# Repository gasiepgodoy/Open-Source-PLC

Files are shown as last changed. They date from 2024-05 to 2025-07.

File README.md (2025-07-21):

# Open-Source-PLC

**Open-Source-PLC** is an open automation platform developed as part of a master's degree project, focused on accessibility, customization, and compatibility with both industrial and educational applications. The goal is to democratize access to industrial automation through a fully open, documented hardware and software solution based on widely adopted technologies.

This repository centralizes all files, documentation, schematics, and source code required to understand, replicate, and extend the system—ensuring long-term continuity and community collaboration.

---

## 🎯 Project Purpose

For an open-source platform to be truly applicable in industrial settings, it must go beyond basic functionality and meet criteria for engineering quality, physical robustness, and scalability. Therefore, the following strategic requirements were defined:

- Full Openness: The project provides complete access to all hardware files (schematics, PCB layout, BOM) and software libraries with public documentation, enabling full transparency, replication, and community-driven evolution.
- Flexibility and Customization: The modular hardware design, combined with support for multiple languages and protocols, allows the platform to be adapted to a variety of processes, from test benches to full-scale industrial lines.
- Industrial Compatibility: The adoption of industrial voltage levels, standard connectors, and protocols such as Modbus and MQTT ensures direct adherence to realworld industrial operating conditions.
- Low Learning Curve: The use of familiar environments (OpenPLC Editor, Thonny IDE) and the development of simplified MicroPython libraries make the platform accessible even to teams with limited experience in advanced programming.
- Experimental Feasibility and Scalability: The architecture has been validated in two distinct setups (PID control and part-sorting station), demonstrating its ability to operate reliably in real applications while remaining scalable for future expansions. 

This combination of elements allows the solution to serve as a bridge between the maker/open-source ecosystem and the technical demands of industry, fostering an environment of continuous innovation, operational cost reduction, and greater technological freedom.

---

## ⚙️ Functional Requirements

- Support for both MicroPython and IEC 61131-3 (via OpenPLC)
- Digital and analog input/output, PWM support
- Ethernet communication (via W5500), with MQTT protocol
- Encoder interface and compatibility with industrial sensors
- Compatibility with standard industrial protocols and connectors
- Modular hardware design with plug-and-play expandability

---

## 🧩 Hardware Summary

The architecture is organized into independent functional blocks, with modular I/O expansion via SPI serialization, allowing the number of inputs and outputs to be tailored to the specific application. The base version of the platform includes:

- **Main controller:** Raspberry Pi Pico (RP2040)
- **Expansion:** Up to 12 digital inputs, 8 digital outputs, 1 dedicated PWM output, 4 analog inputs, and 1 encoder input
- **Networking:** W5500 Ethernet chip with RJ45 connector, SPI communication
- **Electrical Interface:** Level shifters, opto-isolated inputs, and industrial-grade buffers
- **Additional Support:** Optional RS-232/RS-485 communication bus

All schematics and PCB layout files are available in the [`/Hardware`](./Hardware) folder.

---

## 🖥️ Software Summary

The platform offers native support for two complementary paradigms:

### MicroPython
which supports high-level scripting for control, communication, and integration with platforms such as Node-RED, databases, and dashboards.

### OpenPLC
which enables the development of control logic using IEC 61131-3 standardized languages such as Ladder and Structured Text, with an accessible development environment

More details are available in the [`/Software`](./Software) folder.

---

## 🔬 Validation and Testing

Two practical experiments were conducted to validate the system's functionality:

1. **DC Motor PID Control (MicroPython):**
   - Speed control using encoder feedback
   - MQTT communication with Node-RED
   - Validation through manual shaft load variation

2. **Color Sorting Station (OpenPLC):**
   - Color detection with automated part separation
   - Controlled via ladder logic
   - Monitored through MQTT and Node-RED dashboards

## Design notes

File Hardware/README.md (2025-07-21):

# 🧩 Hardware Details – Open-Source-PLC

This section provides an overview of the hardware developed for the Open-Source-PLC platform. The system was designed to be open, modular, and compatible with both industrial devices and educational environments. All design files, schematics, and PCB layouts are included in the repository for replication or adaptation.

---

## 1. 🧱 Architecture Overview

The hardware architecture was based on the following core principles:

- **Modularity:** Independent functional blocks (I/O, communication, power, etc.)
- **Openness:** All design files (schematics, layouts, BOM) are fully available
- **Compatibility:** Designed for use with sensors, actuators, and protocols commonly found in industrial systems
- **Accessibility:** Easily programmable using MicroPython or OpenPLC

---

## 2. 🔧 Main Components

| Component | Description |
|---|---|
| **Microcontroller** | Raspberry Pi Pico (RP2040) |
| **Ethernet Interface** | W5500 chip with SPI interface and RJ45 connector |
| **Digital Inputs** | Up to 12 channels, opto-isolated |
| **Digital Outputs (PWM)**  | 2 PWM-capable outputs with transistor drivers |
| **Analog Inputs** | 4 channels, -10 – 10 V (external sensors, potentiometers) |
| **Encoder Input** | Incremental encoder interface (A/B channels with interrupt support) |
| **Power Supply** | 24 V DC input with onboard voltage regulation |
| **Protection** | ESD protection, buffering, opto-isolators, flyback diodes for outputs |
| **Optional** | RS-232 / RS-485 transceivers for future protocol expansions |

---

## 3. 🧾 PCB and Schematics

All design files are located in the [`hardware`](../hardware) folder. This includes:

- Schematics in PDF and source format (KiCad)
- PCB layout and 3D view files
- Bill of Materials (BOM)
- Gerber files ready for fabrication

---

## 4. 🧰 Assembly and Integration

The hardware is designed to be easily assembled using through-hole and SMD components. Key integration considerations:

- Headers and terminal blocks follow a modular layout for easier cabling
- The platform includes pin labeling and silkscreen guidance
- Power input protection and reverse polarity safeguards included

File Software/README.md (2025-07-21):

# 🧠 Software Implementation Overview – MicroPython and OpenPLC

This document provides a general overview of the software implementations used in the Open-Source-PLC platform. The system was designed to support two complementary development environments:

- **OpenPLC**, an open-source platform that supports IEC 61131-3 programming languages (Ladder, Structured Text, etc.)
- **MicroPython**, a high-level scripting language adapted for microcontrollers, allowing flexible and modular control logic

The goal was to enable the platform to support both industry-standard and educational/research-friendly environments.

---

## 🔷 OpenPLC – IEC 61131-3-Based Programming

OpenPLC was used to validate the compatibility of the hardware with traditional industrial programming standards.

### ✅ Key Features Implemented:
- Integration with **OpenPLC Runtime** on the Raspberry Pi Pico 
- Development of a **color-sorting station** controlled entirely in **Ladder Diagram**
- Use of digital inputs for sensors and digital outputs for actuators
- Real-time monitoring via **MQTT and Node-RED dashboards**

### 🧩 Custom Function Blocks:
To enhance functionality and simplify reuse, custom blocks were created:
- **MQTT Interface Logic:** State variables exposed for integration with Node-RED

### 🧪 Application Example:
- The system uses a color sensor connected to a digital input
- Based on the detected color, an actuator is triggered to sort parts
- Status and results are published to a Node-RED dashboard via MQTT

More technical details will be available in [`OpenPLC/`](../Software/OpenPLC/).

---

## 🟢 MicroPython – Modular High-Level Control

MicroPython was used to develop a fully custom control application and validate the hardware using real-time scripting and communication.

### ✅ Key Features Developed:
- **Modular library** to abstract all I/O operations (Digital I/O, PWM, Analog, Encoder, Ethernet)
- Implementation of a **PID control loop** for DC motor speed using encoder feedback
- Real-time variable update and remote control via **MQTT**
- Integration with **Node-RED** for visualization and manual control

### 📦 Library Modules:
The custom MicroPython library includes:
- `DigitalIO` – digital input/output abstraction
- `PWMOutput` – PWM signal control with frequency and duty cycle options
- `AnalogInput` – basic analog reading with scaling support
- `Encoder` – quadrature encoder interface with real-time position/velocity
- `Ethernet` – W5500 communication interface with DHCP or static IP setup

### 🧪 Application Example:
- A DC motor is controlled via PWM
- An encoder provides speed feedback
- A PID algorithm adjusts the PWM to maintain desired RPM
- MQTT is used to receive setpoints and send actual speed to Node-RED

More technical details will be available in [`Micropython/`](../Software/Micropython/).

---

## 🔄 Coexistence of OpenPLC and MicroPython

Although OpenPLC and MicroPython are used in different contexts, they share the same hardware infrastructure. The platform supports:

- Independent flashing of either OpenPLC Runtime or MicroPython firmware
- Shared access to GPIOs, communication buses, and external interfaces
- Common interfaces with MQTT and Node-RED, allowing seamless monitoring regardless of backend

This dual-approach design enables the platform to be used in:
- **Industrial control scenarios** with standard IEC languages
- **Research and prototyping** using rapid development with MicroPython

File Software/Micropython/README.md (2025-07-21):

# MicroPython Firmware Overview

This section details the developments made using MicroPython on the Open-Source-PLC platform. MicroPython was chosen for its ease of use, flexibility, and compatibility with embedded systems, enabling fast prototyping and direct interaction with hardware.

## Purpose and Justification

The use of MicroPython in this project aimed to:

- Enable a high-level programming alternative to IEC 61131-3, reducing the entry barrier for new users.
- Allow rapid testing and customization of control strategies without complex toolchains.
- Leverage open tools and existing MicroPython support on the RP2040 (Raspberry Pi Pico).

## Firmware Architecture

The firmware follows a modular architecture centered around a custom-developed library named `jaguar`, which abstracts access to the hardware resources of the automation platform.

### Key Modules

- **Digital I/O**: Easy mapping and handling of digital inputs and outputs.
- **Analog I/O**: Support for reading analog sensors and controlling outputs.
- **PWM Output**: Allows precise control of actuators such as motors.
- **Encoder**: Interface for reading motor or shaft position using quadrature encoders.
- **Ethernet (W5500)**: Enables communication with external systems via MQTT over Ethernet.

## Jaguar Library

The core of the firmware is the `jaguar` library, created specifically to make hardware programming more intuitive and abstracted. It provides a set of classes that simplify the use of GPIO, ADC, PWM, encoders, and network connectivity.

### Main Features

- Simple pin mapping system aligned with the platform’s labeling.
- Built-in compatibility with the RP2040 hardware features.
- MQTT-ready interface via W5500 Ethernet chip.
- Easy integration with dashboards and external monitoring tools (e.g., Node-RED).

## MQTT and Real-Time Communication

The firmware uses the `umqtt.simple` library to implement publish/subscribe communication via MQTT. This allows real-time data exchange between the controller and a remote dashboard or data logger.

### Applications

- Remote monitoring of motor speed, encoder position, and control parameters.
- Real-time update of PID parameters from a web interface.
- Logging of system behavior under varying load conditions.

## PID Control Use Case

A complete PID loop was implemented to control a DC motor’s speed using feedback from a quadrature encoder. The system supports real-time adjustment of PID parameters via MQTT and maintains target RPM despite manual load variations.

## Development Environment

- **Firmware Language**: MicroPython (latest stable)
- **IDE**: Thonny IDE
- **Board**: Raspberry Pi Pico
- **Network**: W5500 Ethernet via SPI
- **External Tool**: Node-RED (for visualization)

## Conclusion

The MicroPython firmware, paired with the custom `jaguar` library, enabled the Open-Source-PLC to serve not only as a traditional automation controller but also as a flexible experimentation platform. Its modular design, real-time communication capabilities, and ease of programming make it an ideal solution for educational, experimental, and IIoT applications.

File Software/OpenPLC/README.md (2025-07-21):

# OpenPLC Integration Overview

This section documents the adaptations, extensions, and validation of the OpenPLC framework on the Open-Source-PLC platform. OpenPLC was selected due to its compliance with the IEC 61131-3 standard, open-source nature, and flexibility for embedded applications.

## Purpose and Context

The integration of OpenPLC into the hardware platform aimed to:

- Validate the compatibility of the custom hardware with standard industrial automation software.
- Demonstrate the use of IEC 61131-3 languages (LD, ST, FBD, etc.) on open hardware.
- Provide an alternative path for users familiar with PLC programming.

## Hardware Compatibility

The hardware was adapted to be recognized by the OpenPLC runtime. This included:

- Setting up correct GPIO mapping on the Raspberry Pi Pico (RP2040).
- Developing a compatible hardware layer using the OpenPLC Embedded runtime.
- Ensuring electrical interface compatibility with standard sensors and actuators (24V DC logic, relay modules, etc.).

## Firmware Customizations

Several adaptations were made to the OpenPLC firmware to support the custom hardware:

- **Pin Mapping Layer**: A dedicated mapping file was created to align logical I/Os in the OpenPLC Editor with physical pins on the board.
- **Startup Sequence**: Modified initialization code to work with the board’s peripherals and power-on behavior.
- **I/O Expansion Support**: Extensions to support multiplexed or serialized I/Os.

## Function Block Development

Custom function blocks were developed and tested to enhance OpenPLC’s capabilities:

All blocks were created using the **Structured Text (ST)** language, and are included in the repository as `.st` or `.xml` files for reuse.

## Example Application: Color Sorting Station

A complete application was developed using OpenPLC to automate a color-based separation process.

### Overview

- A TCS230 color sensor detects object color.
- OpenPLC reads the sensor and triggers actuators (e.g., air jets or conveyors) based on the detected color.
- The system is fully programmable and customizable using the OpenPLC Editor.

### Runtime Details

- Program written in OpenPLC Editor (FBD + ST).
- Downloaded to board running OpenPLC Embedded runtime.
- I/Os monitored in real-time via the OpenPLC Web Interface.

## Development Tools

- **Editor**: OpenPLC Editor (IEC 61131-3 compliant)
- **Runtime**: OpenPLC for RP2040 Embedded (customized)

## Conclusion

The successful integration of OpenPLC on the Open-Source-PLC platform demonstrates its suitability for educational and industrial control systems. It enables users to program the controller using standardized IEC languages while benefiting from the openness and flexibility of custom hardware.

This hybrid approach allows for experimentation, interoperability, and easier learning for students and professionals alike.

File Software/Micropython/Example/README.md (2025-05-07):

# Open-Source-PLC - Micropython Validation

To validate the applicability of MicroPython on the developed platform, a detailed test scenario was structured, designed to evaluate the system's capabilities in industrial process control. The experiment involves the implementation of a PID speed control, demonstrating the platform's capabilities in applications that require precision and dynamic response.

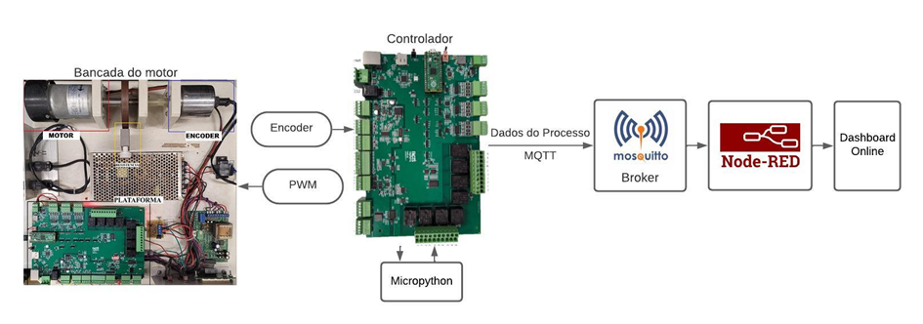
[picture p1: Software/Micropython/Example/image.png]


A video of the experiment can be found at: https://youtu.be/rbEFqCIbv0c?si=TKTA0UZk-yRIU58f

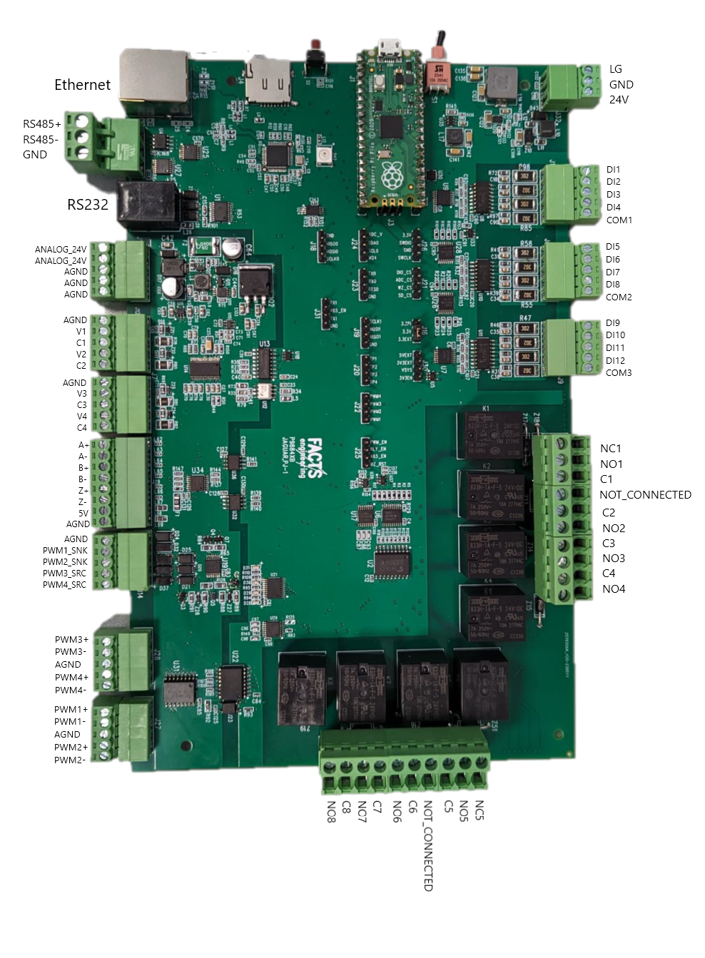
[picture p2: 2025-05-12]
Hardware/Project Pinout.png

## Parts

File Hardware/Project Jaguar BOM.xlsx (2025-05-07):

Level | Item | Part Number | Qty | Refdes | Description | Rev | Vendor | Vendor Part Number
1 | 1 | 1150-00154 | 7 | C1,C5,C7,C9,C48,C56,C81 | .01UF,25V,10%,Ceramic,X7R,0402 | - | TDK | C1005X7R1E103K050BB
1 | 2 | 1150-00120 | 70 | C2-4,C6,C8,C10,C12-14,C17,C19-23,C39,C41,C43,C45,C50-55,C57,C68-69,C72,C74-75,C77,C80,C82-85,C91-92,C94-95,C99-108,C112-113,C115-117,C119,C124-132,C166,C168,C170,C308 | .1UF,50V,10%,Ceramic,X7R,0402 | - | Murata | GRM155R71H104KE14D
 |  |  |  |  |  |  | TDK | C1005X7R1H104K050BB
1 | 4 | 1150-00066 | 1 | C11 | 2200PF,100V,5%,Ceramic,COG,1206 | A1 | AVX | 12061A222JAT2A
 |  |  |  |  |  |  | Prosperity Dielectrics Co., Ltd. | MA1206CG-222J-101PRG
 |  |  |  |  |  |  | Yageo America | CC1206JRNPO0BN222
 |  |  |  |  |  |  | SINCERA-WALSIN | 1206N222J101LT
1 | 7 | 1150-00014 | 13 | C18,C31-38,C42,C88-90 | .1UF,100V,10%,Ceramic,X7R,0805 | A1 | Murata | GCM21BR72A104KA37L
 |  |  |  |  |  |  | Prosperity Dielectrics Co., Ltd. | MA0805XR-104K-101PRG
 |  |  |  |  |  |  | SINCERA-WALSIN | 0805B104K101CT
1 | 9 | 1150-00050 | 9 | C15,C24,C26-28,C30,C40,C65,C67 | 1UF,10V,10%,Ceramic,X5R,0603 | A1 | AVX | 0603ZD105KAT2A
 |  |  |  |  |  |  | Prosperity Dielectrics Co., Ltd. | MA0603XR-105K-100PRG
 |  |  |  |  |  |  | SINCERA-WALSIN | 0603X105K160CT
1 | 10 | 1150-00029 | 3 | C25,C141-142 | 22UF,25V,+/-10%,Ceramic,X5R,1206 | - | Murata | GRM31CR61E226KE15L
 |  |  |  |  |  |  | SINCERA-WALSIN | 1206X226K250CT
 |  |  |  |  |  |  | Prosperity Dielectrics Co., Ltd. | MA1206XR-226K-250PRG
 |  |  |  |  |  |  | Samsung | CL31A226KAHNNNE
1 | 13 | 1150-00004 | 7 | C16,C44,C70,C76,C78-79,C109 | .001UF,50V,10%,Ceramic,X7R,0603 | A1 | Murata | GRM188R71H102KA01D
 |  |  |  |  |  |  | Prosperity Dielectrics Co., Ltd. | MA0603XR-102K-500PRG
 |  |  |  |  |  |  | Yageo America | CC0603KRX7R9BB102
 |  |  |  |  |  |  | SINCERA-WALSIN | 0603B102K500CT
1 | 14 | 1150-00178 | 4 | C29,C46-47,C140 | 10UF,10V,10%,Ceramic,X5R,0603 | - | Murata | GRM188R61A106KE69J
 |  |  |  |  |  |  | AVX | 0603ZD106KAT2A
 |  |  |  |  |  |  | TDK | C1608X5R1A106K080AC
 |  |  |  |  |  |  | Yageo America | CC0603KRX5R6BB106
1 | 16 | 1150-00007 | 1 | C123 | .01UF,50V,10%,Ceramic,X7R,0603 | A1 | Murata | GRM188R71H103KA01D
 |  |  |  |  |  |  | Yageo Corporation | CC0603KRX7R9BB103
 |  |  |  |  |  |  | Prosperity Dielectrics Co., Ltd. | MA0603XR-103K-500PRG
 |  |  |  |  |  |  | SINCERA-WALSIN | 0603B103K500CT
1 | 17 | 1150-00081 | 4 | C58-59,C61-62 | 4.7UF,25V,20%,Ceramic,X5R,0805 | A1 | Panasonic | ECJ-2FB1E475M
 |  |  |  |  |  |  | SINCERA-WALSIN | 0805X475K250CT
 |  |  |  |  |  |  | Prosperity Dielectrics Co., Ltd. | MA0805XR-475K-250PRG
 |  |  |  |  |  |  | Murata | GRM21BR61E475MA12L
1 | 18 | 1150-00084 | 1 | C63 | 470PF,50V,5%,Ceramic,COG,0805 | A1 | AVX | 08055A471JAT2A
 |  |  |  |  |  |  | Prosperity Dielectrics Co., Ltd. | MA0805CG-471J-PRG
 |  |  |  |  |  |  | SINCERA-WALSIN | 0805N471J500LT
1 | 19 | 1160-00016 | 1 | C64 | 22UF,50V,20%,Electrolytic,2000H@105C,6.3X5.8MM | A | Gemcon | GDX022M050-0605TR
1 | 20 | 1160-00021 | 2 | C66,C121 | 100UF,16V,20%,Electrolytic,2000H@105C,6.3X5.4mm | A | Gemcon | GCK100M016-0605TR
 |  |  |  |  |  |  | Gemcon | GDR100M016-0605TR
 |  |  |  |  |  |  | Nichicon | UWX1C101MCL1GB
1 | 21 | 1150-00002 | 3 | C49,C71,C73 | 4.7UF,10V,10%,Ceramic,X5R,0603 | A1 | Tai Yao | LMK107BJ475KA-T
 |  |  |  |  |  |  | Samsung | CL10A475KP8NNNC
 |  |  |  |  |  |  | Walsin Technology Corporation | 0603X475K160CT
1 | 23 | 1150-00063 | 6 | C86-87,C93,C96-98 | 20PF,50V,5%,Ceramic,COG,0603 | A1 | Murata | GRM1885C1H220JA01D
 |  |  |  |  |  |  | Prosperity Dielectrics Co., Ltd. | MA0603CG-200J-500PRG
 |  |  |  |  |  |  | SINCERA-WALSIN | 0603N200J500LT
1 | 27 | 1150-00064 | 1 | C122 | 2200PF,50V,10%,Ceramic,X7R,0603 | A1 | AVX | 06035C222KAT2A
1 | 28 | 1150-00041 | 1 | C135 | 10UF,35V,+/-10%,Ceramic,X5R,1206 | - | Taiyo Yuden | GMK316BJ106KL-T
1 | 29 | 1150-00118 | 1 | C139 | 27PF,50V,5%,Ceramic,COG,0402 | - | Murata | GRM1555C1H270JA01D
1 | 30 | 1375-00017 | 24 | D1-16,D28-31,D38-41 | LED,SMD,1.6x.8MM,Red | B1 | Taiwan Oasis | TO-1608BC-MRE
 |  |  |  |  |  |  | Harvatek | HT-191USD-DT
1 | 31 | 1300-00028 | 1 | D18 | Diode,Schottky,B1100,SMA | A1 | Diodes Inc | B1100-13-F
1 | 32 | 1375-00019 | 6 | D19,D22-23,D26-27,D34 | LED,SMD,3x1MM,Right Angle,Green | A1 | Taiwan Oasis | TO-3210AC-MGE (E2-E4)
 |  |  |  |  |  |  | Harvatek | HT-110UYG-CT
1 | 33 | 1350-00026 | 4 | D20-21,D24-25 | TVS, Unidirectional,SMAJ28A-TR,32.7V,400W,DO-214AC | - | ST | SMAJ28A-TR
 |  |  |  |  |  |  | Willas | SMAJ28A-TG
 |  |  |  |  |  |  | Goodwork | SMAJ28A
1 | 34 | 1300-00044 | 5 | D32-33,D36-37,D44 | Diode,Schottky,5819,SMA | A2 | SEP Electronics | SM5819
 |  |  |  |  |  |  | Formosa MS | FM5819
1 | 35 | 1300-00088 | 1 | D35 | Diode,Schottky,MBR0530T1G,SOD-123 | - | ON Semiconductor | MBR0530T1G
 |  |  |  |  |  |  | CZ | B0530W
1 | 36 | 1375-00035 | 1 | D42 | LED,SMD, Right Angle, 3.8x1.0MM, RGB with Integrated Serial Driver | - | RAMTRONICS INDUSTRIAL CO., LTD. | KR-3810
1 | 37 | 1300-00067 | 1 | D43 | Diode,Schottky,SM240A,SMA | A | GW | SM240A
 |  |  |  |  |  |  | Willas | SS24A
 |  |  |  |  |  |  | Diodes Inc | B240A-13-F
1 | 38 | 3001-00011 | 2 | J1-2 | Pin Header,1x20,2.54MM,SIP,Straight | - | AUK Contractors | HD1x20
1 | 39 | 3001-00001 | 2 | J3,J16 | Pin Header,1x3,2.54MM,SIP,Straight | - | AUK Contractors | HD1x03
1 | 40 | 3000-00110 | 1 | J4 | MircoSD,SMD,Receptical,9 | A1 | King Font | TFCMF-30801B0T1
 |  |  |  |  |  |  | King Font | TFCMF-30801B0T1-G
1 | 41 | 3000-00102 | 1 | J5 | RJ45,Shielded,With XFMR, RX/TX LEDS,12 | - | Kinsun | 3070130108
1 | 42 | 3030-00008 | 9 | J6-7,J9-12,J14,J27-28 | Terminal Block Socket,3.5MM,Right Angle,Closed End,Green,5 | A1 | Dinkle | ECH350R-05P
1 | 43 | 3030-00026 | 2 | J8,J15 | Terminal Block Socket,5MM,Vertical Angle, Closed End, Green,10 | - | Dinkle | 5EHDVC-10P
1 | 44 | 3030-00003 | 1 | J13 | Terminal Block Socket,5MM,Right Angle,Closed End,Green,3 | B1 | Dinkle | 5EHDRC-03P
1 | 45 | 3000-00037 | 1 | J17 | RJ12,Side,6 | A | Kinsun | 3004BE3600
1 | 46 | 3001-00002 | 10 | J18-26,J30 | Pin Header,1x4,2.54MM,SIP,Straight | - | AUK Contractors | HD1x-04
1 | 48 | 3030-00022 | 1 | J32 | Terminal Block Socket,3.5MM,Right Angle,Closed End,Green,Raised,3 | - | Dinkle | ECH350H-03P
1 | 49 | 3200-00026 | 2 | K1,K5 | Relay,1C,24VDC,277VAC/10A,125VAC/15A,30VDC/7A,833H-1C-24 | - | Song Chuan | 833H-1C-F-S-24VDC
1 | 50 | 3200-00027 | 6 | K2-4,K6-8 | Relay,1A,24VDC,277VAC/10A,125VAC/15A,30VDC/7A,833H-1A-24 | A | Song Chuan | 833H-1A-F-S-24VDC
1 | 51 | 1550-00008 | 4 | L1-4 | Ferrite,33 Ohm @100MHZ,0603 | A1 | Murata | BLM18PG330SN1D
 |  |  |  |  |  |  | Chilisin Electronics Corp | PBY160808T-330Y-N
 |  |  |  |  |  |  | VIKING | CB03YTYH330
1 | 52 | 1550-00003 | 1 | L5 | Ferrite,470 Ohm @100MHZ,0805 | A | Murata | BLM21AG471SN1D
1 | 53 | 1550-00007 | 2 | L6,L13 | Ferrite,220 Ohm @100MHZ,0603 | A1 | Murata | BLM18BD221SN1D
 |  |  |  |  |  |  | ABC Taiwan Electronics | MU1608221Y2B
1 | 54 | 1550-00006 | 6 | L7,L9,L11-12,L68-69 | Ferrite,330 Ohm @100MHZ,0805 | B2 | TDK | MPZ2012S331AT
 |  |  |  |  |  |  | ABC Taiwan Electronics | MB2029331Y2B
 |  |  |  |  |  |  | Hilisin | PBY201209T-331Y-N
1 | 55 | 1500-00056 | 1 | L8 | Inductor,Power,Shielded Ferrite Core,SMD,22UH,530MA | A | ABC Taiwan Electronics | SH4022220YLB
1 | 56 | 1500-00119 | 1 | L10 | Inductor,Chip Common Mode Choke Coil,1.4K @100MHz,2.0A | - | Murata Manufacturing | DLW5BTM142TQ2
1 | 57 | 1500-00010 | 1 | L14 | Inductor,Power,Shielded Ferrite Core,SMD,100UH,1.25A | - | Chilisin Electronics Corp | SCDS105RT-101-N
1 | 58 | 1500-00034 | 1 | L17 | Inductor,Power,Shielded Ferrite Core,SMD,2.2UH,1.6A | B | ABC Taiwan Electronics | SH40222R2YLB
1 | 59 | 1550-00004 | 2 | L25-26 | Ferrite,60 Ohm @100MHZ,0805 | A1 | Murata | BLM21PG600SN1D
 |  |  |  |  |  |  | Chilisin Electronics Corp | BBPY00201209600Y00
 |  |  |  |  |  |  | ABC Taiwan Electronics | MB2029221Y3B
1 | 61 | 1550-00014 | 6 | L62-67 | Ferrite,1K @100MHZ,0402 | - | Chilisin Electronics Corp | HFY100505T-102Y-N
 |  |  |  |  |  |  | Murata | BLM15HG102SN1D
1 | 62 | 1200-00006 | 1 | Q1 | Transistor,PNP,MMBT2907,SOT23 | B1 | Diodes Inc | MMBT2907A-7-F
 |  |  |  |  |  |  | ON Semiconductor | MMBT2907A
 |  |  |  |  |  |  | Micro Commercial Components | MMBT2907A-TP
1 | 63 | 1250-00030 | 4 | Q3-4,Q6,Q16 | FET,N-CH/P-CH Pair,60V,500MA,1.7 Ohm/4 Ohm | - | Diodes Inc | DMG1029SV-7
 |  |  |  |  |  |  | Vishay | SI1029X-T1-GE3
1 | 64 | 1250-00035 | 1 | Q5 | FET,N-Channel,Dual,60V,115MA,7.5 Ohm | A | Fairchild Semiconductor | 2N7002DW
 |  |  |  |  |  |  | Diodes Inc | 2N7002DW-7
1 | 65 | 1250-00036 | 1 | Q11 | FET,P-Channel,Single,Logic Level,60V,1.25A,.170 Ohm | A | Fairchild Semiconductor | FDN5618P
 |  |  |  |  |  |  | Potens Semiconductor Corp. | PDN6911S
 |  |  |  |  |  |  | Panjit | PJA3439-AU_R1_000A1
1 | 66 | 1025-00015 | 18 | R1,R31,R39-46,R65,R72,R84,R86,R88,R90,R97,R128 | 1.2K,0805,5%,1/8W | A | Yageo Corporation | RC0805JR-071K2L
 |  |  |  |  |  |  | SINCERA-WALSIN | WR08X122JTL
1 | 67 | 1025-00245 | 20 | R2-5,R10-11,R16-17,R19-26,R100,R102-104 | 475,0603,1%,1/10W | A | ROHM | MCR03EZPFX4750
 |  |  |  |  |  |  | Panasonic | ERJ-3EKF4750V
 |  |  |  |  |  |  | SINCERA-WALSIN | WR06X4750FTL
 |  |  |  |  |  |  | Yageo Corporation | RC0603FR-07475RL
1 | 68 | 1025-00248 | 4 | R6-9 | 49.9,0603,1%,1/10W | A1 | ROHM | MCR03EZPFX49R9
 |  |  |  |  |  |  | Panasonic | ERJ-3EKF49R9V
 |  |  |  |  |  |  | Yageo America | RC0603FR-0749R9L
 |  |  |  |  |  |  | SINCERA-WALSIN | WR06X49R9FTL
1 | 69 | 1025-00463 | 26 | R12,R14,R18,R52,R59-63,R74,R83,R105-108,R120-126,R129,R136,R142,R149 | 10K,0402,1%,1/16W,100PPM | - | Yageo Corporation | RC0402FR-0710KL
1 | 70 | 1025-00362 | 3 | R13,R28,R131 | 330,0402,.5%,1/16W,25PPM | A | Panasonic | ERA-2AED331X
 |  |  |  |  |  |  | VIKING | AR02DTCY3300
1 | 71 | 1025-00464 | 1 | R15 | 10,0402,1%,1/16W,100PPM | - | KOA | RK73H1ETTP10R0F
1 | 73 | 1025-00383 | 12 | R27,R29-30,R47,R55-58,R85,R87,R96,R98 | 3K,2512,5%,2W,200PPM | - | Walsin Technology Corporation | WF25P302JTL
1 | 74 | 1025-00121 | 24 | R32-33,R68,R70,R76-77,R99,R111-119,R133,R137-138,R143-144,R146-148 | 1K,0603,1%,1/10W | A1 | Panasonic | ERJ-3EKF1001V
 |  |  |  |  |  |  | SINCERA-WALSIN | WR06X1001FTL
 |  |  |  |  |  |  | Yageo Corporation | RC0603FR-071KL
1 | 75 | 1025-00223 | 1 | R34 | 4.75K,0805,.5%,1/10W,25ppm | A | Susumu | RR1220P-4751-D-M
 |  |  |  |  |  |  | VIKING | AR05DTCX4751
 |  |  |  |  |  |  | Susumu | RG2012P-4751-D-T5
1 | 77 | 1025-00207 | 4 | R36-38,R49 | 33,0603,1%,1/10W | A1 | ROHM | MCR03EZPFX33R0
 |  |  |  |  |  |  | Yageo Corporation | RC0603FR-0733RL
 |  |  |  |  |  |  | SINCERA-WALSIN | WR06X33R0FTL
1 | 78 | 1025-00065 | 1 | R48 | 12.4K,0603,1%,1/10W | A1 | Yageo Corporation | RC0603FR-0712K4L
 |  |  |  |  |  |  | SINCERA-WALSIN | WR06X1242FTL
1 | 79 | 1025-00254 | 4 | R50-51,R53,R150 | 49.9K,0603,1%,1/10W | A | Panasonic | ERJ-3EKF4992V
 |  |  |  |  |  |  | SINCERA-WALSIN | WR06X4992FTL
 |  |  |  |  |  |  | Yageo Corporation | RC0603FR-0749K9L
1 | 81 | 1025-00377 | 1 | R54 | 40.2K,0603,.1%,1/16W,25ppm | A | VIKING | AR03BTC4022
 |  |  |  |  |  |  | Walsin Technology Corporation | WF06U4022BTL
1 | 84 | 1025-00031 | 4 | R66-67,R69,R71 | 100,0805,1%,1/8W | A1 | Panasonic | ERJ-6ENF1000V
 |  |  |  |  |  |  | Yageo Corporation | RC0805FR-07100RL
 |  |  |  |  |  |  | SINCERA-WALSIN | WR08X1000FTL
1 | 85 | 1025-00010 | 1 | R73 | 1.15K,0805,.5%,1/10W,25PPM | A1 | Yageo Corporation | RT0805DRD071K15
 |  |  |  |  |  |  | VIKING | AR05DTCX1151
1 | 87 | 1025-00294 | 1 | R75 | 75K,0603,1%,1/10W | A1 | ROHM | MCR03EZPFX7502
 |  |  |  |  |  |  | Panasonic | ERJ-3EKF7502V
 |  |  |  |  |  |  | SINCERA-WALSIN | WR06X7502FTL
 |  |  |  |  |  |  | Yageo Corporation | RC0603FR-0775KL
1 | 88 | 1025-00175 | 4 | R78,R80-82 | 250,1210,.1%,1/3W,25PPM | A1 | VIKING | AR13BTCO2500
1 | 89 | 1025-00276 | 2 | R35,R79 | 6.8K,0805,.5%,1/10W,25ppm | A | Susumu | RR1220P-682-D
 |  |  |  |  |  |  | VIKING | AR05DTCX6801
 |  |  |  |  |  |  | Susumu | RG2012P-682-D-T5
1 | 91 | 1025-00261 | 3 | R89,R91-92 | 5.76K,0805,1%,1/8W | A1 | Panasonic | ERJ-6ENF5761V
 |  |  |  |  |  |  | SINCERA-WALSIN | WR08X5761FTL
 |  |  |  |  |  |  | Yageo Corporation | RC0805FR-075K76L
1 | 92 | 1025-00333 | 1 | R93 | 665,0603,1%,1/10W | - | Panasonic | ERJ-3EKF6650V
1 | 93 | 1025-00240 | 4 | R94-95,R109-110 | 470,0603,5%,1/10W | A1 | Panasonic | ERJ-3GEYJ471V
 |  |  |  |  |  |  | Yageo America | RC0603JR-07470RL
 |  |  |  |  |  |  | SINCERA-WALSIN | WR06X471JTL
1 | 94 | 1025-00032 | 1 | R101 | 100K,0603,.1%,1/16W,25PPM | A | Susumu | RR0816P-104-B-T5
 |  |  |  |  |  |  | Panasonic | ERA-3AEB104V
 |  |  |  |  |  |  | VIKING | AR03BTCY1003
 |  |  |  |  |  |  | Susumu | RG1608P-104-B-T5
1 | 95 | 1025-00442 | 1 | R127 | 150,0402,1%,1/16W,100PPM | - | Yageo Corporation | RC0402FR-07150RL
1 | 96 | 1025-00005 | 6 | R64,R130,R135,R139-141 | 0,0603,5%,1/10W | A1 | Yageo Corporation | RC0603JR-070RL
1 | 98 | 1025-00260 | 1 | R132 | 5.49K,0805,.5%,1/10W,25ppm | A | Susumu | RR1220P-5491-D-M
 |  |  |  |  |  |  | VIKING | AR05DTCX5491
 |  |  |  |  |  |  | Susumu | RG2012P-5491-D-T5
1 | 100 | 1025-00300 | 1 | R134 | 8.2K,0805,5%,1/8W | A1 | Panasonic | ERJ-6GEYJ822V
 |  |  |  |  |  |  | SINCERA-WALSIN | WR08X822JTL
 |  |  |  |  |  |  | Yageo Corporation | RC0805JR-078K2L
1 | 103 | 1025-00359 | 1 | R145 | 45.3K,0805,.5%,1/10W,25ppm | A | Susumu | RR1220P-4532-D-M
 |  |  |  |  |  |  | VIKING | AR05DTCX4532
 |  |  |  |  |  |  | Susumu | RG2012P-4532-D-T5
1 | 104 | 1025-00028 | 5 | R169,R171,R187-189 | 100,0603,5%,1/10W | A1 | Yageo Corporation | RC0603JR-07100R
 |  |  |  |  |  |  | SINCERA-WALSIN | WR06X101JTL
1 | 105 | 3100-00014 | 1 | S1 | Switch,Sub-Mini,Toggle,ESD-9kVDC,1,SPDT,Right Angle | - | Salecom Electronics CO. LTD. | ES-6-P2-Q-S-H
1 | 106 | 3100-00011 | 1 | S2 | Switch,Tactile,Momentary,1,SPST,Right Angle | C | E-Switch | TL1105RF250Q
 |  |  |  |  |  |  | Diptronics Manufacturing Inc. | DTSA-648R-V
1 | 107 | 2350-00013 | 1 | U1 | RS-232,Dual,Transmitter/Receiver,ADM3222ARU,TSSOP20 | A | Analog Devices | ADM3222ARUZ
1 | 108 | 2330-00004 | 1 | U2 | 8 Channel,Common Emitters,Darlington Trans,5V In TTL/CMOS,SOL18 | B2 | Toshiba | TBD62083AFWG
 |  |  |  |  |  |  | UTC | UNL2803L-S18-T
 |  |  |  |  |  |  | Toshiba | ULN2803AFWG(C, ELHA
 |  |  |  |  |  |  | Toshiba | ULN2803AFWG(C,EL
1 | 109 | 2350-00059 | 1 | U3 | Ethernet,Single,Tranceiver,W5500,QFSP7X7-48N | - | WIZnet | W5500
1 | 110 | 2350-00014 | 1 | U4 | RS-485/422,Single,Tranceiver,ADM3485,SO8NB | A | Analog Devices | ADM3485EARZ
1 | 111 | 2000-00072 | 3 | U5,U7,U9 | Inverter,Hex,Schmitt-Trigger,74LCX14,TSSOP14 | A1 | Fairchild Semiconductor | 74LCX14MTC
1 | 112 | 2000-00042 | 1 | U6 | Buffer,Octal,Inverting,3-State,74LVC540A,TSSOP20 | - | AVNET | SN74LVC540APWR
1 | 113 | 2400-00042 | 3 | U8,U10-11 | Isolator-Optical,Quad,100%,TLP292-4 | - | Toshiba | TLP292-4(LGBTP,E
1 | 114 | 2400-00008 | 1 | U12 | Isolator-Optical,Single,100%,FOD2742B | A1 | Fairchild Semiconductor | FOD2742B
1 | 115 | 2400-00004 | 1 | U13 | Isolator-Digital,Quad,3 Tx/1 Rx,-,SI8641AB-B-IS1 | - | Silicon Labs | Si8641AB-B-IS1
 |  |  |  |  |  |  | Skyworks Solutions, Inc. | SI8641BB-B-IS1
1 | 116 | 2305-00032 | 1 | U14 | SAR,ADC,16-Bit,Octal,SPI,500 kSPS,ADS8688IDBTR | - | Texas Instruments | ADS8688IDBTR
1 | 117 | 2315-00009 | 1 | U15 | Bandgap,Voltage Reference,4.096V,.05%,10PPM,TSOT23-6 | - | Linear Tech | LT6654AHS6-4.096#TRPBF
1 | 118 | 1400-00027 | 1 | U16 | Linear Regulator,LP2992-3.3,3.3V,250MA | A1 | Texas Instruments | LP2992IM5-3.3/NOPB
1 | 119 | 2000-00052 | 2 | U17,U29 | Shift Register,8-Bit,3-State,74AHC595,SSOP16N | A2 | Texas Instruments | 74AHC595PW
 |  |  |  |  |  |  | NXP | 74AHC595PW,118
 |  |  |  |  |  |  | Fairchild Semiconductor | 74VHC595MTCX
1 | 121 | 2000-00125 | 1 | U19 | AND,Quad,2-Input,74AHC08,TSSOP14 | - | NXP | 74AHC08PW,112
 |  |  |  |  |  |  | Texas Instruments | SN74AHC08PW
1 | 122 | 1425-00084 | 1 | U20 | Current Mode, Buck Converter,210KHZ,6V-30V,Adj | - | Active-Semi, Inc. | ACT4065ASH-T
1 | 123 | 2000-00074 | 1 | U21 | Buffer,Octal,3-State,74LCX541,TSSOP20 | A | ON Semiconductor | MC74LCX541DTR2G
 |  |  |  |  |  |  | Toshiba | 74LCX541FT(AE)
 |  |  |  |  |  |  | Nexperia | 74LVC541APW,118
 |  |  |  |  |  |  | Texas Instruments | SN74LVC541APWR
 |  |  |  |  |  |  | Fairchild Semiconductor | 74LCX541MTC
 |  |  |  |  |  |  | ON Semiconductor | 74LCX541MTCX
1 | 124 | 2400-00058 | 1 | U22 | Isolator-Digital,Quad,4 Tx/0 Rx,1Mbps,SI8640AB-B-IS | - | Silicon Labs | Si8640AB-B-IS
1 | 125 | 2400-00016 | 1 | U23 | Isolator-Optical,Single,50%,LTV-356T | A1 | LITE-ON Technology | LTV-356T
1 | 127 | 2000-00081 | 1 | U25 | OR,Quad,2-Input,74LVX32,TSSOP14 | A1 | Fairchild Semiconductor | 74LVX32MTCX
1 | 128 | 2000-00060 | 2 | U26,U28 | Shift Register,8-Bit,74HC165,TSSOP16 | A1 | Fairchild Semiconductor | MM74HC165MTC
 |  |  |  |  |  |  | Texas Instruments | SN74HC165PW
 |  |  |  |  |  |  | NXP | 74HC165PW,112
1 | 129 | 2000-00079 | 1 | U27 | Inverter,Hex,74LVX04,TSSOP14 | A1 | Fairchild Semiconductor | 74LVX04MTCX
1 | 130 | 1250-00088 | 1 | U30 | FET,P-Channel,Single,30V,9A,.015 Ohm | - | ST | STL9P3LLH6
1 | 131 | 2350-00046 | 1 | U31 | RS-485/422,Quad,Differential Line Driver,SN75LBC172A,SO16WB | - | Texas Instruments | SN75LBC172A16DWR
1 | 132 | 2400-00059 | 2 | U32,U36 | Isolator-Digital,Dual,2 Tx/0 Rx,SI8620BB-B-IS | - | Silicon Labs | SI8620BB-B-ISR
1 | 133 | 2350-00031 | 1 | U34 | RS-422/423,Quad,Differential Line Receiver,ST26C32A,TSSOP16 | A | ST | ST26C32ABTR
1 | 134 | 1425-00075 | 1 | U35 | Step-Down,1MHZ,2.7V-5.5V,2A,Adj | - | Diodes Inc | AP3402KTTR-G1
 |  |  |  |  |  |  | Elite Semiconductor | EML3320-00VN06NRR
1 | 135 | 1425-00037 | 1 | U111 | Hysteretic PFET Buck Controller,4.5V - 35V,Adj | A1 | Texas Instruments | LM3485MMX/NOPB
 |  |  |  |  |  |  | Texas Instruments | LM3485MM/NOPB
1 | 136 | 1625-00013 | 1 | Y3 | Oscillator,25MHZ,OSCS22-25 | - | Yuechung International Corp | OSC25M-3.3/S22-25T
1 | 137 | 1350-00018 | 3 | Z6-8 | TVS,Bidirectional,1SMA10CAT3,11.69V,400W,SMA-NP | A2 | ON Semiconductor | 1SMA10CAT3G
 |  |  |  |  |  |  | SONGFU ELECTRONICS CO. LTD | SMAJ10CA
 |  |  |  |  |  |  | Littelfuse | SMAJ10CA
 |  |  |  |  |  |  | Vishay | SMAJ10CA-E3/61
1 | 138 | 1350-00003 | 10 | Z9,Z13-19,Z51-52 | TVS,Bidirectional,P4KE350CA,350V,400W,TVS1 | A1 | Vishay | P4KE350CA
 |  |  |  |  |  |  | Goodwork | P4KE350CA
 |  |  |  |  |  |  | Littelfuse | P4KE350CA
1 | 139 | 1350-00014 | 1 | Z10 | TVS,Bidirectional,SMAJ30CA,35V,400W,DO-214AC-NP | A1 | Vishay | SMAJ30CA-E3/61
1 | 140 | 1350-00019 | 1 | Z20 | TVS,Bidirectional,1SMA33CAT3G,38.63V,400W,SMA-NP | B1 | CZ | SMAJ33CA-CZ
 |  |  |  |  |  |  | ON Semiconductor | 1SMA33CAT3G
 |  |  |  |  |  |  | ST | SMAJ33CA-TR
 |  |  |  |  |  |  | Littelfuse | SMAJ33CA
1 | 141 | 1350-00036 | 4 | Z21-24 | TVS,Bidirectional,Low Cap/Leakage,SP4022-01FTG-C,13.3V,500W,SOD-323 | - | Littelfuse | SP4022-01FTG-C
1 | 142 | 1325-00014 | 2 | Z27-28 | Diode,Zener,DDZ20ASF,20V,.5W,SOD-323F | - | Diodes Inc | DDZ20ASF-7
 |  |  |  |  |  |  | Goodwork | MMSZ5248BS
1 | 143 | 1300-00041 | 1 | D17 | Diode,Schottky,MBRS340T3,DO-214AB | A | ON Semiconductor | MBRS340T3G
1 | 144 | 3030-00009 | 1 | J29 | Terminal Block Socket,3.5MM,Right Angle,Closed End,Green,8 | A1 | Dinkle | ECH350R-08P
1 | 146 | 3400-00038 | 1 | F2 | Fuse,Resettable,PTC,2920,1A | - | BEL FUSE | 0ZCF0100AF2A
1 | 147 | 2050-00031 | 1 | U24 | EEPROM,Serial,2-Wire,I2C,5MS,128 x 8,24C01A-2.7 | A2 | Seiko Instruments Inc. | S-24C01CI-T8T1U
 |  |  |  |  |  |  | ST | M24C01-RDW6TP
 |  |  |  |  |  |  | Atmel | AT24C01A-10TU-2.7
 |  |  |  |  |  |  | ST | M24C01-WDW6TP
1 | 148 | 1150-00159 | 2 | C118,C120 | 10UF,50V,10%,Ceramic,X5R,1206 | - | TDK | C3216X5R1H106K160AB
 |  |  |  |  |  |  | Samsung | CL31A106KBHNNNE
 |  |  |  |  |  |  | Murata | GRM31CR61H106KA12L
 |  |  |  |  |  |  | Taiyo Yuden | UMK316BBJ106KL-T
1 | 149 | 1150-00177 | 2 | C133-134 | 10UF,25V,10%,Ceramic,X5R,0805 | - | Murata | GJ821BR61E106KE11L
 |  |  |  |  |  |  | TDK | C2012X5R1E106K085AC
 |  |  |  |  |  |  | Taiyo Yuden | TMK212BBJ106KG-T
 |  |  |  |  |  |  | Yageo America | CC0805KKX5R8BB106
1 | 150 | 3400-00036 | 1 | F1 | Fuse,Resettable PTC,1206,16VDC,250MA | - | Littelfuse | 1206L025YR
1 | 151 | 1400-00002 | 1 | Q2 | Linear Regulator,7805,5V,1A | A2 | ON Semiconductor | MC7805CD2TG
 |  |  |  |  |  |  | ST | L7805CD2T-TR
 |  |  |  |  |  |  | GLOBALTECH Semi | GS7805LMF

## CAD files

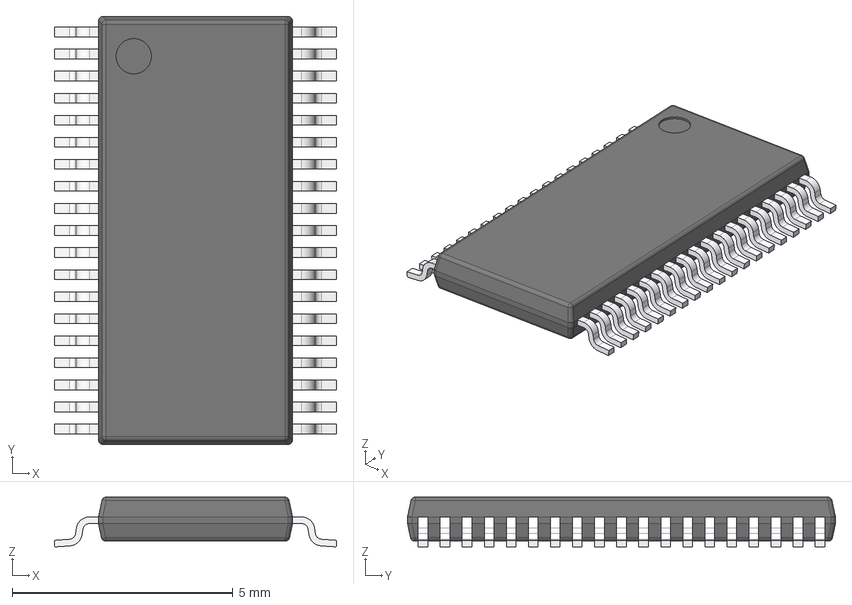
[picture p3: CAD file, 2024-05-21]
Hardware/KiCad Files/Components/3D/ADS8688IDBTR.stp
6.40 x 9.70 x 1.13 mm
BODY-TSSOP
LEAD-TSSOP x 38
PIN1

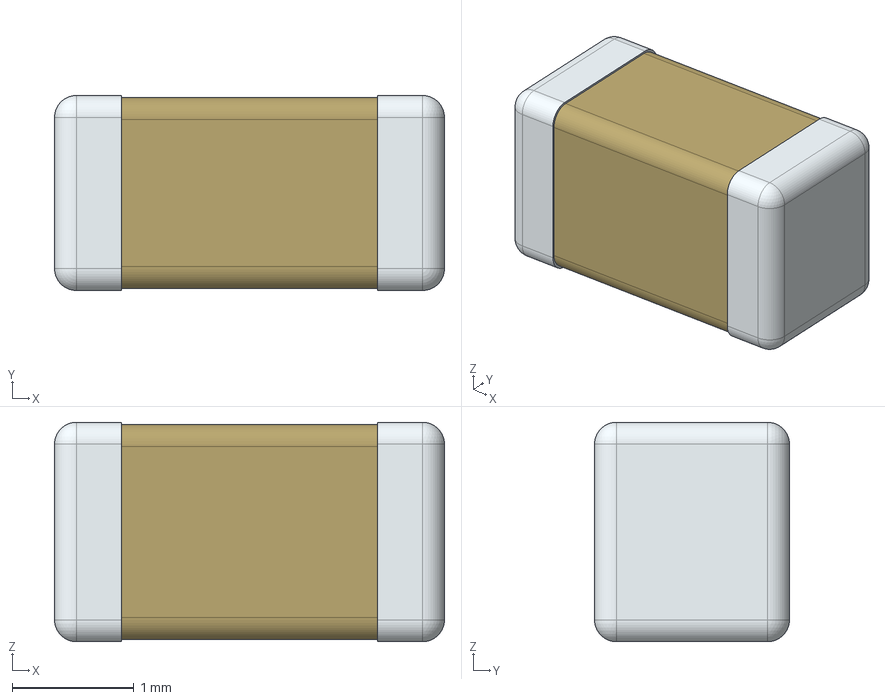
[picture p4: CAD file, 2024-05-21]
Hardware/KiCad Files/Components/3D/GRM31CR61H106KA12L.stp
3.20 x 1.60 x 1.80 mm

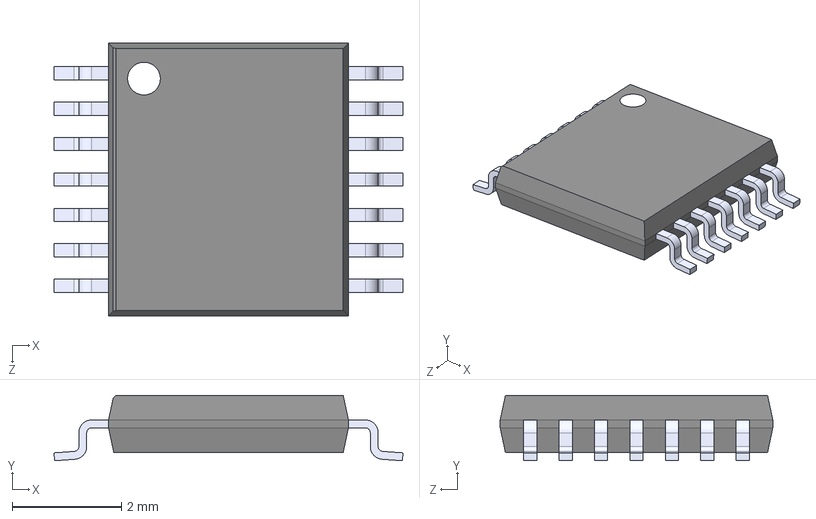
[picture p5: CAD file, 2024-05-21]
Hardware/KiCad Files/Components/3D/74LVX32MTC.STEP
6.40 x 1.20 x 5.00 mm

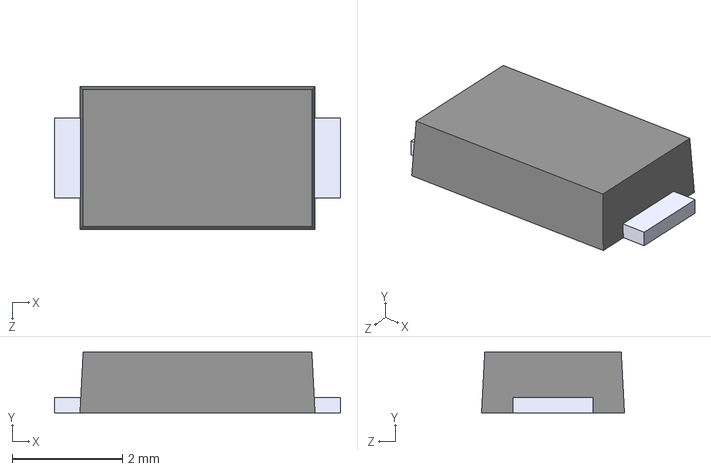
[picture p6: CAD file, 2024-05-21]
Hardware/KiCad Files/Components/3D/SMAJ28A-TR.STEP
5.20 x 1.10 x 2.60 mm

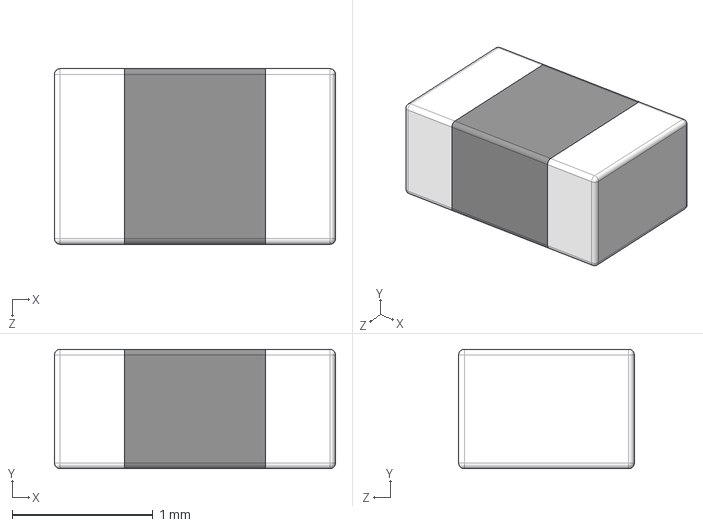
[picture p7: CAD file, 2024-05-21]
Hardware/KiCad Files/Components/3D/BLM21PG600SN1D.stp
2.00 x 0.85 x 1.25 mm

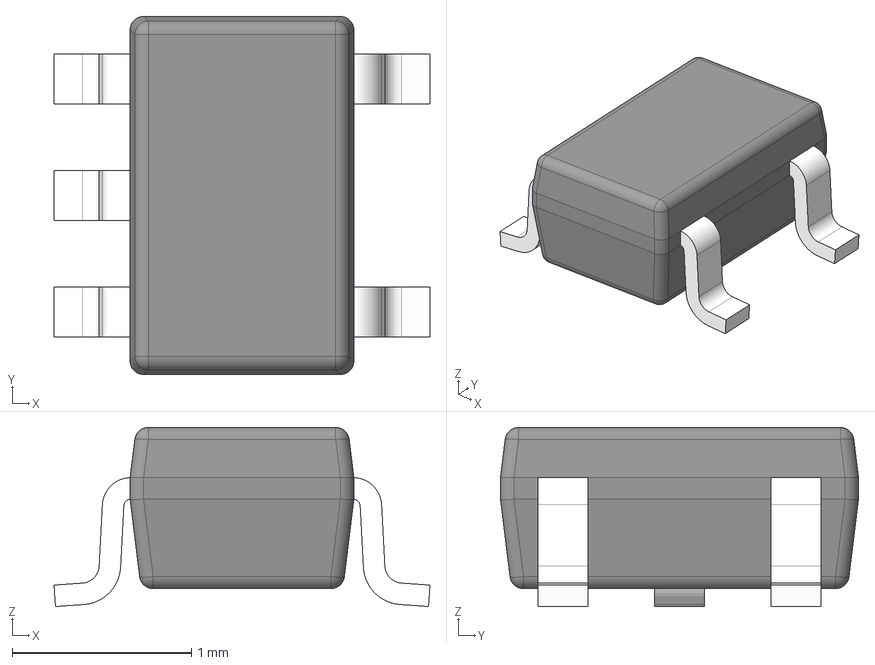
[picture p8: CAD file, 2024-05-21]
Hardware/KiCad Files/Components/3D/SN74LVC1G14QDCKRQ1.stp
2.10 x 2.00 x 1.00 mm
BODY-SOT
LEAD-SOT x 5
PIN1-ID

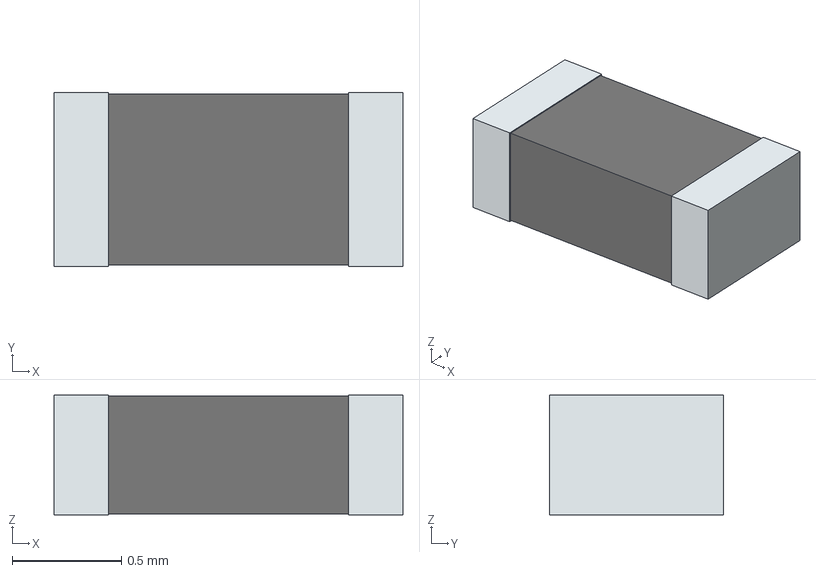
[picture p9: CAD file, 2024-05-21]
Hardware/KiCad Files/Components/3D/RC0603JR-07100RL.stp
1.60 x 0.8 x 0.55 mm
term1
term2

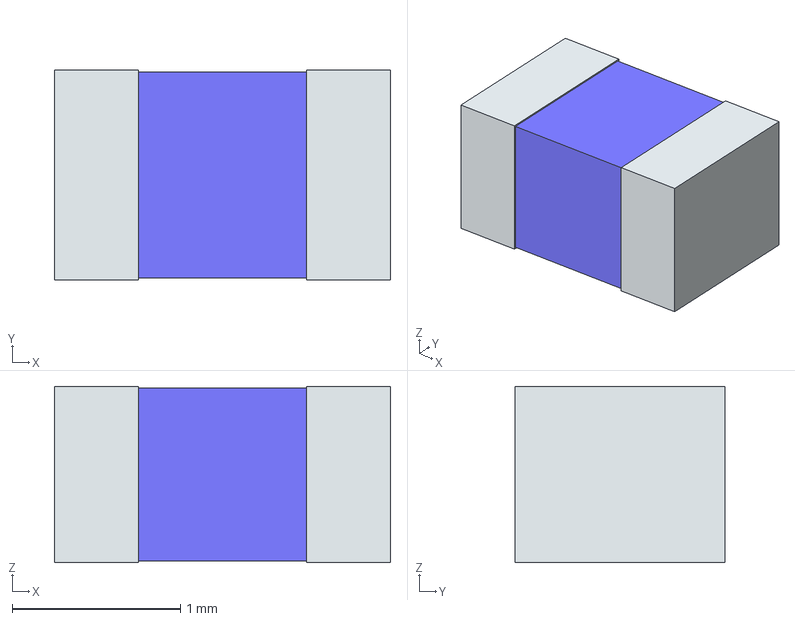
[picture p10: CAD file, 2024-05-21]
Hardware/KiCad Files/Components/3D/MPZ2012S331AT000.stp
2.00 x 1.25 x 1.05 mm
term1
term2

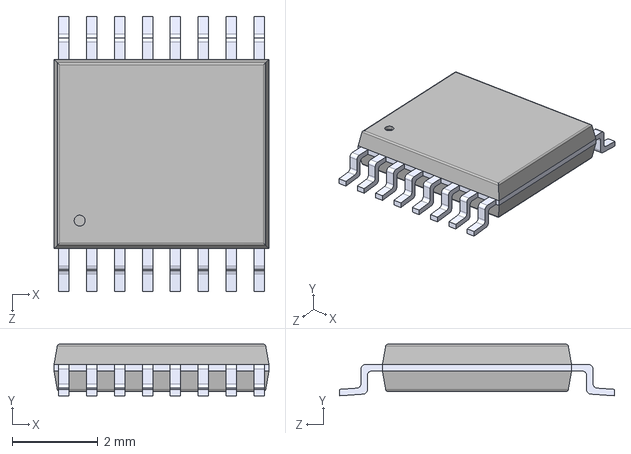
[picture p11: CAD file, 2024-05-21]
Hardware/KiCad Files/Components/3D/SN74AHC595PW.STEP
5.00 x 1.20 x 6.40 mm

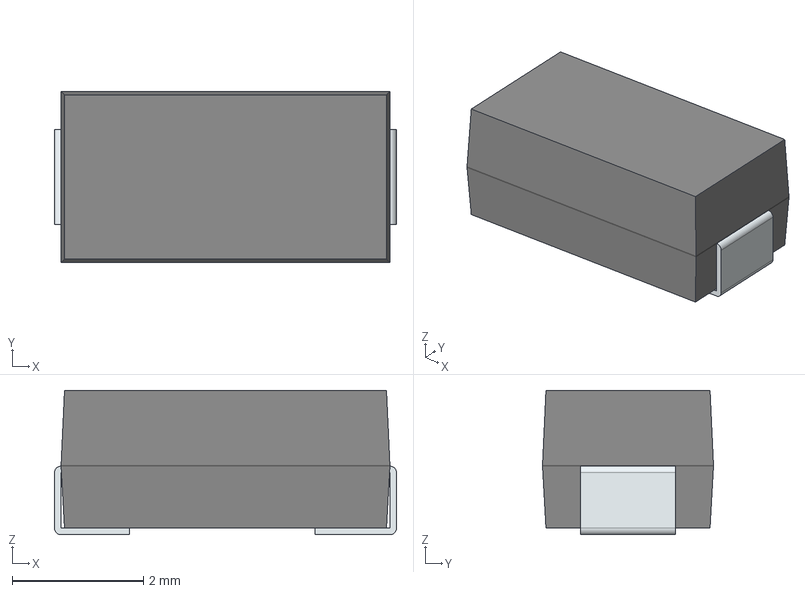
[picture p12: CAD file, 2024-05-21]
Hardware/KiCad Files/Components/3D/SZ1SMA33CAT3G.stp
5.21 x 2.60 x 2.20 mm
FilletPin1
FilletPin2

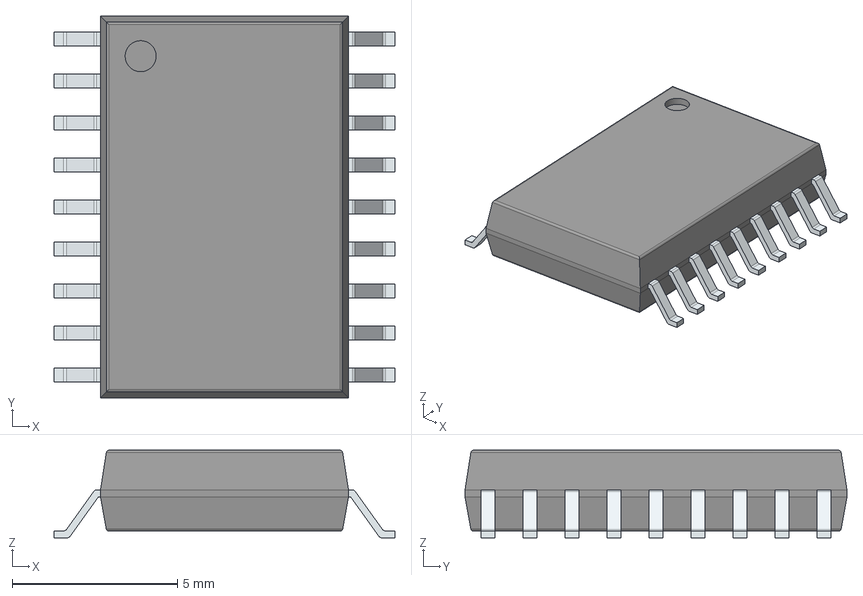
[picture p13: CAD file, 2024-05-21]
Hardware/KiCad Files/Components/3D/ULN2803AFWG_C,ELHA.stp
10.3 x 11.6 x 2.65 mm
PinsArrayLR

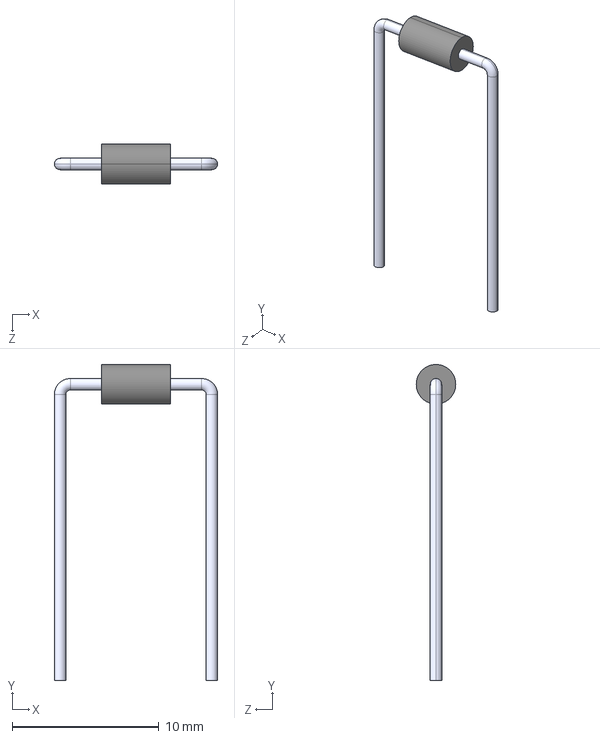
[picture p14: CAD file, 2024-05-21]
Hardware/KiCad Files/Components/3D/P4KE350CA.STEP
11.1 x 21.6 x 2.70 mm

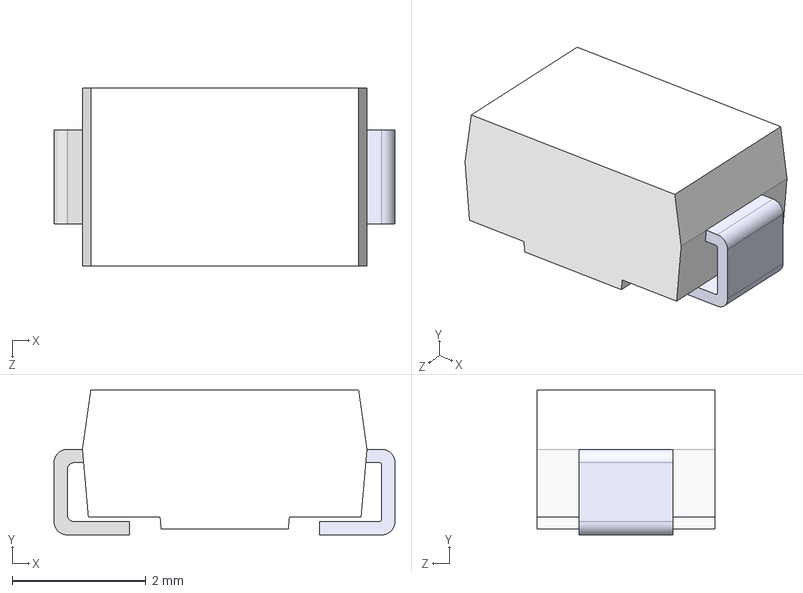
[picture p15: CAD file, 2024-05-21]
Hardware/KiCad Files/Components/3D/SMAJ30CA-E3_61.stp
5.09 x 2.17 x 2.67 mm

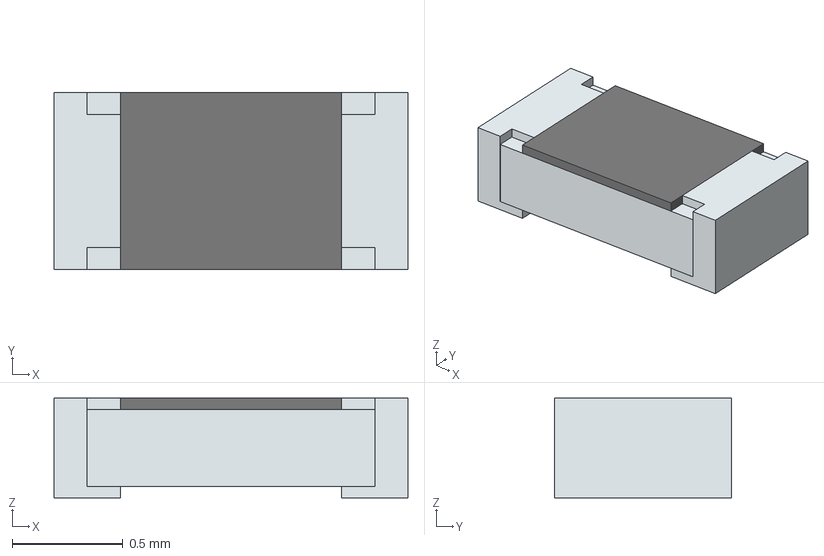
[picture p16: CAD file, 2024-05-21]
Hardware/KiCad Files/Components/3D/ERJ-3EKF1001V.stp
1.60 x 0.8 x 0.45 mm
solidBody
Terminal
solidTop

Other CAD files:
Hardware/KiCad Files/Components/3D/GMK316BJ106KL-T.stp
Hardware/KiCad Files/Components/3D/SM5819PL-TP--3DModel-STEP-56544.STEP
Hardware/KiCad Files/Components/3D/MPZ2012S331AT.stp
Hardware/KiCad Files/Components/3D/74LCX14MTC.stp
Hardware/KiCad Files/Components/3D/06035C222KAT2A.stp
Hardware/KiCad Files/Components/3D/0603ESDA2-TR2.stp
Hardware/KiCad Files/Components/3D/0603ZD105KAT2A.stp
Hardware/KiCad Files/Components/3D/08055A471JAT2A.stp
Hardware/KiCad Files/Components/3D/0ZCF0100AF2A.stp
Hardware/KiCad Files/Components/3D/100SP1T2B4M6QE--3DModel-STEP-613395.STEP
Hardware/KiCad Files/Components/3D/100SP1T2B4M6QE.step
Hardware/KiCad Files/Components/3D/12061A222JAT2A.stp
Hardware/KiCad Files/Components/3D/1206L025YR.stp
Hardware/KiCad Files/Components/3D/1705950-1.stp
Hardware/KiCad Files/Components/3D/1SMA10CAT3G.stp
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

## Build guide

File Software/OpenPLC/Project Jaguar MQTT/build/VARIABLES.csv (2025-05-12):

// Programs
0 | CONFIG0.RES0.INSTANCE0 | PROGRAM0
// Variables
0 | FB | CONFIG0.RES0.INSTANCE0 | CONFIG0.RES0.INSTANCE0 | PROGRAM0
1 | VAR | CONFIG0.RES0.INSTANCE0.MQTT_CONNECTED | CONFIG0.RES0.INSTANCE0.MQTT_CONNECTED | BOOL
2 | FB | CONFIG0.RES0.INSTANCE0.MQTT_SEND1 | CONFIG0.RES0.INSTANCE0.MQTT_SEND1 | MQTT_SEND
3 | VAR | CONFIG0.RES0.INSTANCE0.MQTT_SEND1.EN | CONFIG0.RES0.INSTANCE0.MQTT_SEND1.EN | BOOL
4 | VAR | CONFIG0.RES0.INSTANCE0.MQTT_SEND1.ENO | CONFIG0.RES0.INSTANCE0.MQTT_SEND1.ENO | BOOL
5 | VAR | CONFIG0.RES0.INSTANCE0.MQTT_SEND1.SEND | CONFIG0.RES0.INSTANCE0.MQTT_SEND1.SEND | BOOL
6 | VAR | CONFIG0.RES0.INSTANCE0.MQTT_SEND1.TOPIC | CONFIG0.RES0.INSTANCE0.MQTT_SEND1.TOPIC | STRING
7 | VAR | CONFIG0.RES0.INSTANCE0.MQTT_SEND1.MESSAGE | CONFIG0.RES0.INSTANCE0.MQTT_SEND1.MESSAGE | STRING
8 | VAR | CONFIG0.RES0.INSTANCE0.MQTT_SEND1.SUCCESS | CONFIG0.RES0.INSTANCE0.MQTT_SEND1.SUCCESS | BOOL
9 | FB | CONFIG0.RES0.INSTANCE0.MQTT_CONNECT0 | CONFIG0.RES0.INSTANCE0.MQTT_CONNECT0 | MQTT_CONNECT
10 | VAR | CONFIG0.RES0.INSTANCE0.MQTT_CONNECT0.EN | CONFIG0.RES0.INSTANCE0.MQTT_CONNECT0.EN | BOOL
11 | VAR | CONFIG0.RES0.INSTANCE0.MQTT_CONNECT0.ENO | CONFIG0.RES0.INSTANCE0.MQTT_CONNECT0.ENO | BOOL
12 | VAR | CONFIG0.RES0.INSTANCE0.MQTT_CONNECT0.CONNECT | CONFIG0.RES0.INSTANCE0.MQTT_CONNECT0.CONNECT | BOOL
13 | VAR | CONFIG0.RES0.INSTANCE0.MQTT_CONNECT0.BROKER | CONFIG0.RES0.INSTANCE0.MQTT_CONNECT0.BROKER | STRING
14 | VAR | CONFIG0.RES0.INSTANCE0.MQTT_CONNECT0.PORT | CONFIG0.RES0.INSTANCE0.MQTT_CONNECT0.PORT | UINT
15 | VAR | CONFIG0.RES0.INSTANCE0.MQTT_CONNECT0.SUCCESS | CONFIG0.RES0.INSTANCE0.MQTT_CONNECT0.SUCCESS | BOOL
16 | FB | CONFIG0.RES0.INSTANCE0.TON0 | CONFIG0.RES0.INSTANCE0.TON0 | TON
17 | VAR | CONFIG0.RES0.INSTANCE0.TON0.EN | CONFIG0.RES0.INSTANCE0.TON0.EN | BOOL
18 | VAR | CONFIG0.RES0.INSTANCE0.TON0.ENO | CONFIG0.RES0.INSTANCE0.TON0.ENO | BOOL
19 | VAR | CONFIG0.RES0.INSTANCE0.TON0.IN | CONFIG0.RES0.INSTANCE0.TON0.IN | BOOL
20 | VAR | CONFIG0.RES0.INSTANCE0.TON0.PT | CONFIG0.RES0.INSTANCE0.TON0.PT | TIME
21 | VAR | CONFIG0.RES0.INSTANCE0.TON0.Q | CONFIG0.RES0.INSTANCE0.TON0.Q | BOOL
22 | VAR | CONFIG0.RES0.INSTANCE0.TON0.ET | CONFIG0.RES0.INSTANCE0.TON0.ET | TIME
23 | VAR | CONFIG0.RES0.INSTANCE0.TON0.STATE | CONFIG0.RES0.INSTANCE0.TON0.STATE | SINT
24 | VAR | CONFIG0.RES0.INSTANCE0.TON0.PREV_IN | CONFIG0.RES0.INSTANCE0.TON0.PREV_IN | BOOL
25 | VAR | CONFIG0.RES0.INSTANCE0.TON0.CURRENT_TIME | CONFIG0.RES0.INSTANCE0.TON0.CURRENT_TIME | TIME
26 | VAR | CONFIG0.RES0.INSTANCE0.TON0.START_TIME | CONFIG0.RES0.INSTANCE0.TON0.START_TIME | TIME
27 | IN | CONFIG0.RES0.INSTANCE0.TURNON | CONFIG0.RES0.INSTANCE0.TURNON | BOOL
28 | IN | CONFIG0.RES0.INSTANCE0.TURNOFF | CONFIG0.RES0.INSTANCE0.TURNOFF | BOOL
29 | IN | CONFIG0.RES0.INSTANCE0.RESET | CONFIG0.RES0.INSTANCE0.RESET | BOOL
30 | IN | CONFIG0.RES0.INSTANCE0.PARTSENSOR | CONFIG0.RES0.INSTANCE0.PARTSENSOR | BOOL
31 | IN | CONFIG0.RES0.INSTANCE0.INDUCTIVE | CONFIG0.RES0.INSTANCE0.INDUCTIVE | BOOL
32 | IN | CONFIG0.RES0.INSTANCE0.PHOTOELECTRIC | CONFIG0.RES0.INSTANCE0.PHOTOELECTRIC | BOOL
33 | IN | CONFIG0.RES0.INSTANCE0.PASSING | CONFIG0.RES0.INSTANCE0.PASSING | BOOL
34 | OUT | CONFIG0.RES0.INSTANCE0.CONVEYOR | CONFIG0.RES0.INSTANCE0.CONVEYOR | BOOL
35 | OUT | CONFIG0.RES0.INSTANCE0.ACTUATOR1 | CONFIG0.RES0.INSTANCE0.ACTUATOR1 | BOOL
36 | OUT | CONFIG0.RES0.INSTANCE0.ACTUATOR2 | CONFIG0.RES0.INSTANCE0.ACTUATOR2 | BOOL
37 | OUT | CONFIG0.RES0.INSTANCE0.BLOCK | CONFIG0.RES0.INSTANCE0.BLOCK | BOOL
38 | VAR | CONFIG0.RES0.INSTANCE0.MEMORY | CONFIG0.RES0.INSTANCE0.MEMORY | BOOL
39 | VAR | CONFIG0.RES0.INSTANCE0.MEMORY1 | CONFIG0.RES0.INSTANCE0.MEMORY1 | BOOL
40 | VAR | CONFIG0.RES0.INSTANCE0.MEMORY2 | CONFIG0.RES0.INSTANCE0.MEMORY2 | BOOL
41 | VAR | CONFIG0.RES0.INSTANCE0.MEMORY3 | CONFIG0.RES0.INSTANCE0.MEMORY3 | BOOL
42 | VAR | CONFIG0.RES0.INSTANCE0.SILVERMEMORY | CONFIG0.RES0.INSTANCE0.SILVERMEMORY | BOOL
43 | VAR | CONFIG0.RES0.INSTANCE0.BLACKMEMORY | CONFIG0.RES0.INSTANCE0.BLACKMEMORY | BOOL
44 | VAR | CONFIG0.RES0.INSTANCE0.REDMEMORY | CONFIG0.RES0.INSTANCE0.REDMEMORY | BOOL
45 | FB | CONFIG0.RES0.INSTANCE0.MQTT_SEND2 | CONFIG0.RES0.INSTANCE0.MQTT_SEND2 | MQTT_SEND
46 | VAR | CONFIG0.RES0.INSTANCE0.MQTT_SEND2.EN | CONFIG0.RES0.INSTANCE0.MQTT_SEND2.EN | BOOL
47 | VAR | CONFIG0.RES0.INSTANCE0.MQTT_SEND2.ENO | CONFIG0.RES0.INSTANCE0.MQTT_SEND2.ENO | BOOL
48 | VAR | CONFIG0.RES0.INSTANCE0.MQTT_SEND2.SEND | CONFIG0.RES0.INSTANCE0.MQTT_SEND2.SEND | BOOL
49 | VAR | CONFIG0.RES0.INSTANCE0.MQTT_SEND2.TOPIC | CONFIG0.RES0.INSTANCE0.MQTT_SEND2.TOPIC | STRING
50 | VAR | CONFIG0.RES0.INSTANCE0.MQTT_SEND2.MESSAGE | CONFIG0.RES0.INSTANCE0.MQTT_SEND2.MESSAGE | STRING
51 | VAR | CONFIG0.RES0.INSTANCE0.MQTT_SEND2.SUCCESS | CONFIG0.RES0.INSTANCE0.MQTT_SEND2.SUCCESS | BOOL
52 | FB | CONFIG0.RES0.INSTANCE0.MQTT_SEND3 | CONFIG0.RES0.INSTANCE0.MQTT_SEND3 | MQTT_SEND
53 | VAR | CONFIG0.RES0.INSTANCE0.MQTT_SEND3.EN | CONFIG0.RES0.INSTANCE0.MQTT_SEND3.EN | BOOL
54 | VAR | CONFIG0.RES0.INSTANCE0.MQTT_SEND3.ENO | CONFIG0.RES0.INSTANCE0.MQTT_SEND3.ENO | BOOL
55 | VAR | CONFIG0.RES0.INSTANCE0.MQTT_SEND3.SEND | CONFIG0.RES0.INSTANCE0.MQTT_SEND3.SEND | BOOL
56 | VAR | CONFIG0.RES0.INSTANCE0.MQTT_SEND3.TOPIC | CONFIG0.RES0.INSTANCE0.MQTT_SEND3.TOPIC | STRING
57 | VAR | CONFIG0.RES0.INSTANCE0.MQTT_SEND3.MESSAGE | CONFIG0.RES0.INSTANCE0.MQTT_SEND3.MESSAGE | STRING
58 | VAR | CONFIG0.RES0.INSTANCE0.MQTT_SEND3.SUCCESS | CONFIG0.RES0.INSTANCE0.MQTT_SEND3.SUCCESS | BOOL
59 | FB | CONFIG0.RES0.INSTANCE0.MQTT_SEND4 | CONFIG0.RES0.INSTANCE0.MQTT_SEND4 | MQTT_SEND
60 | VAR | CONFIG0.RES0.INSTANCE0.MQTT_SEND4.EN | CONFIG0.RES0.INSTANCE0.MQTT_SEND4.EN | BOOL
61 | VAR | CONFIG0.RES0.INSTANCE0.MQTT_SEND4.ENO | CONFIG0.RES0.INSTANCE0.MQTT_SEND4.ENO | BOOL
62 | VAR | CONFIG0.RES0.INSTANCE0.MQTT_SEND4.SEND | CONFIG0.RES0.INSTANCE0.MQTT_SEND4.SEND | BOOL
63 | VAR | CONFIG0.RES0.INSTANCE0.MQTT_SEND4.TOPIC | CONFIG0.RES0.INSTANCE0.MQTT_SEND4.TOPIC | STRING
64 | VAR | CONFIG0.RES0.INSTANCE0.MQTT_SEND4.MESSAGE | CONFIG0.RES0.INSTANCE0.MQTT_SEND4.MESSAGE | STRING
65 | VAR | CONFIG0.RES0.INSTANCE0.MQTT_SEND4.SUCCESS | CONFIG0.RES0.INSTANCE0.MQTT_SEND4.SUCCESS | BOOL
66 | FB | CONFIG0.RES0.INSTANCE0.MQTT_SEND5 | CONFIG0.RES0.INSTANCE0.MQTT_SEND5 | MQTT_SEND
67 | VAR | CONFIG0.RES0.INSTANCE0.MQTT_SEND5.EN | CONFIG0.RES0.INSTANCE0.MQTT_SEND5.EN | BOOL
68 | VAR | CONFIG0.RES0.INSTANCE0.MQTT_SEND5.ENO | CONFIG0.RES0.INSTANCE0.MQTT_SEND5.ENO | BOOL
69 | VAR | CONFIG0.RES0.INSTANCE0.MQTT_SEND5.SEND | CONFIG0.RES0.INSTANCE0.MQTT_SEND5.SEND | BOOL
70 | VAR | CONFIG0.RES0.INSTANCE0.MQTT_SEND5.TOPIC | CONFIG0.RES0.INSTANCE0.MQTT_SEND5.TOPIC | STRING
71 | VAR | CONFIG0.RES0.INSTANCE0.MQTT_SEND5.MESSAGE | CONFIG0.RES0.INSTANCE0.MQTT_SEND5.MESSAGE | STRING
72 | VAR | CONFIG0.RES0.INSTANCE0.MQTT_SEND5.SUCCESS | CONFIG0.RES0.INSTANCE0.MQTT_SEND5.SUCCESS | BOOL
73 | FB | CONFIG0.RES0.INSTANCE0.MQTT_SEND6 | CONFIG0.RES0.INSTANCE0.MQTT_SEND6 | MQTT_SEND
74 | VAR | CONFIG0.RES0.INSTANCE0.MQTT_SEND6.EN | CONFIG0.RES0.INSTANCE0.MQTT_SEND6.EN | BOOL
75 | VAR | CONFIG0.RES0.INSTANCE0.MQTT_SEND6.ENO | CONFIG0.RES0.INSTANCE0.MQTT_SEND6.ENO | BOOL
76 | VAR | CONFIG0.RES0.INSTANCE0.MQTT_SEND6.SEND | CONFIG0.RES0.INSTANCE0.MQTT_SEND6.SEND | BOOL
77 | VAR | CONFIG0.RES0.INSTANCE0.MQTT_SEND6.TOPIC | CONFIG0.RES0.INSTANCE0.MQTT_SEND6.TOPIC | STRING
78 | VAR | CONFIG0.RES0.INSTANCE0.MQTT_SEND6.MESSAGE | CONFIG0.RES0.INSTANCE0.MQTT_SEND6.MESSAGE | STRING
79 | VAR | CONFIG0.RES0.INSTANCE0.MQTT_SEND6.SUCCESS | CONFIG0.RES0.INSTANCE0.MQTT_SEND6.SUCCESS | BOOL
80 | FB | CONFIG0.RES0.INSTANCE0.MQTT_SEND7 | CONFIG0.RES0.INSTANCE0.MQTT_SEND7 | MQTT_SEND
81 | VAR | CONFIG0.RES0.INSTANCE0.MQTT_SEND7.EN | CONFIG0.RES0.INSTANCE0.MQTT_SEND7.EN | BOOL
82 | VAR | CONFIG0.RES0.INSTANCE0.MQTT_SEND7.ENO | CONFIG0.RES0.INSTANCE0.MQTT_SEND7.ENO | BOOL
83 | VAR | CONFIG0.RES0.INSTANCE0.MQTT_SEND7.SEND | CONFIG0.RES0.INSTANCE0.MQTT_SEND7.SEND | BOOL
84 | VAR | CONFIG0.RES0.INSTANCE0.MQTT_SEND7.TOPIC | CONFIG0.RES0.INSTANCE0.MQTT_SEND7.TOPIC | STRING
85 | VAR | CONFIG0.RES0.INSTANCE0.MQTT_SEND7.MESSAGE | CONFIG0.RES0.INSTANCE0.MQTT_SEND7.MESSAGE | STRING
86 | VAR | CONFIG0.RES0.INSTANCE0.MQTT_SEND7.SUCCESS | CONFIG0.RES0.INSTANCE0.MQTT_SEND7.SUCCESS | BOOL
87 | FB | CONFIG0.RES0.INSTANCE0.MQTT_SEND8 | CONFIG0.RES0.INSTANCE0.MQTT_SEND8 | MQTT_SEND
88 | VAR | CONFIG0.RES0.INSTANCE0.MQTT_SEND8.EN | CONFIG0.RES0.INSTANCE0.MQTT_SEND8.EN | BOOL
89 | VAR | CONFIG0.RES0.INSTANCE0.MQTT_SEND8.ENO | CONFIG0.RES0.INSTANCE0.MQTT_SEND8.ENO | BOOL
90 | VAR | CONFIG0.RES0.INSTANCE0.MQTT_SEND8.SEND | CONFIG0.RES0.INSTANCE0.MQTT_SEND8.SEND | BOOL
91 | VAR | CONFIG0.RES0.INSTANCE0.MQTT_SEND8.TOPIC | CONFIG0.RES0.INSTANCE0.MQTT_SEND8.TOPIC | STRING
92 | VAR | CONFIG0.RES0.INSTANCE0.MQTT_SEND8.MESSAGE | CONFIG0.RES0.INSTANCE0.MQTT_SEND8.MESSAGE | STRING
93 | VAR | CONFIG0.RES0.INSTANCE0.MQTT_SEND8.SUCCESS | CONFIG0.RES0.INSTANCE0.MQTT_SEND8.SUCCESS | BOOL
// Ticktime
20000000

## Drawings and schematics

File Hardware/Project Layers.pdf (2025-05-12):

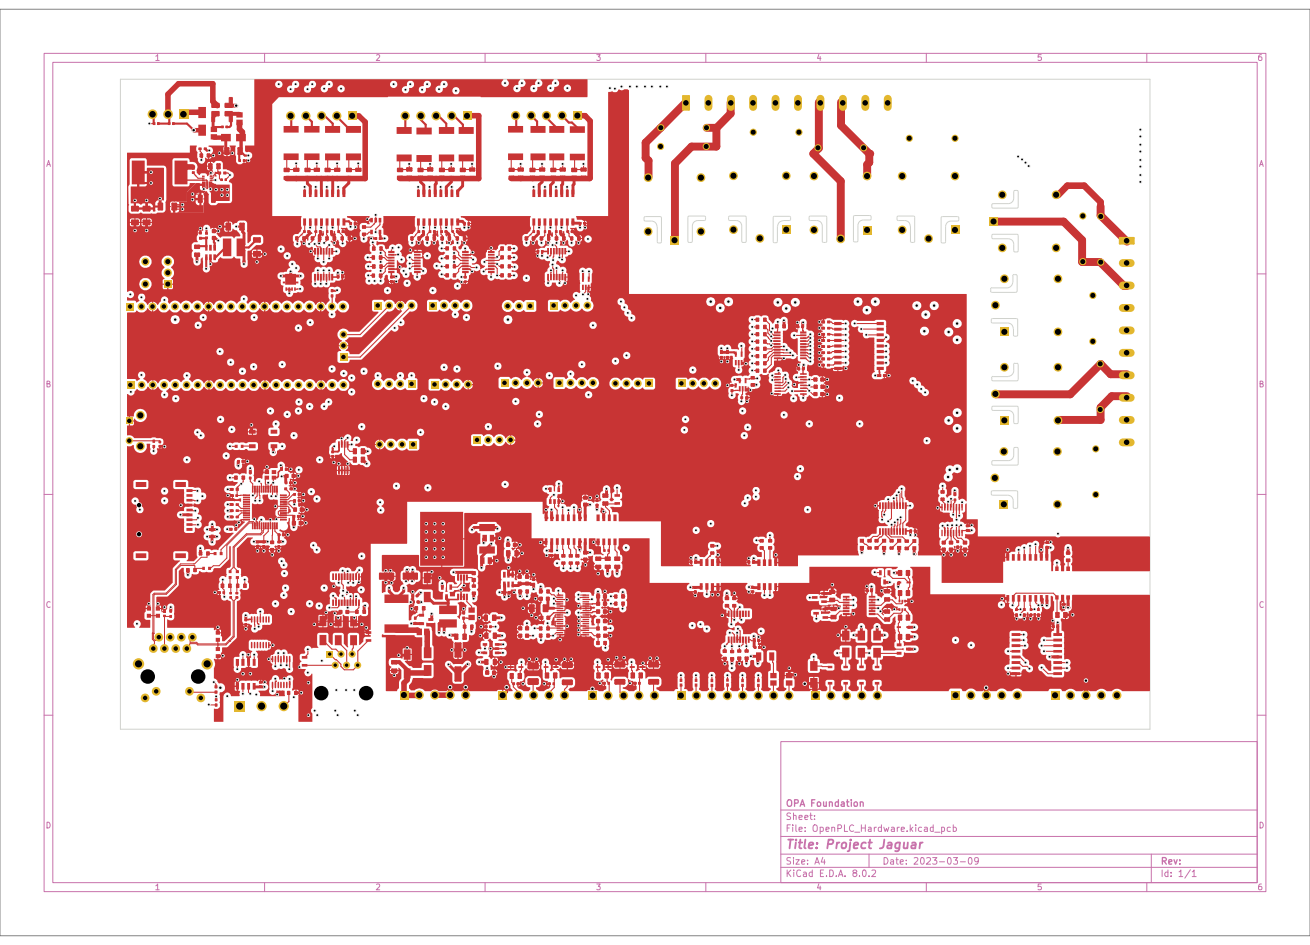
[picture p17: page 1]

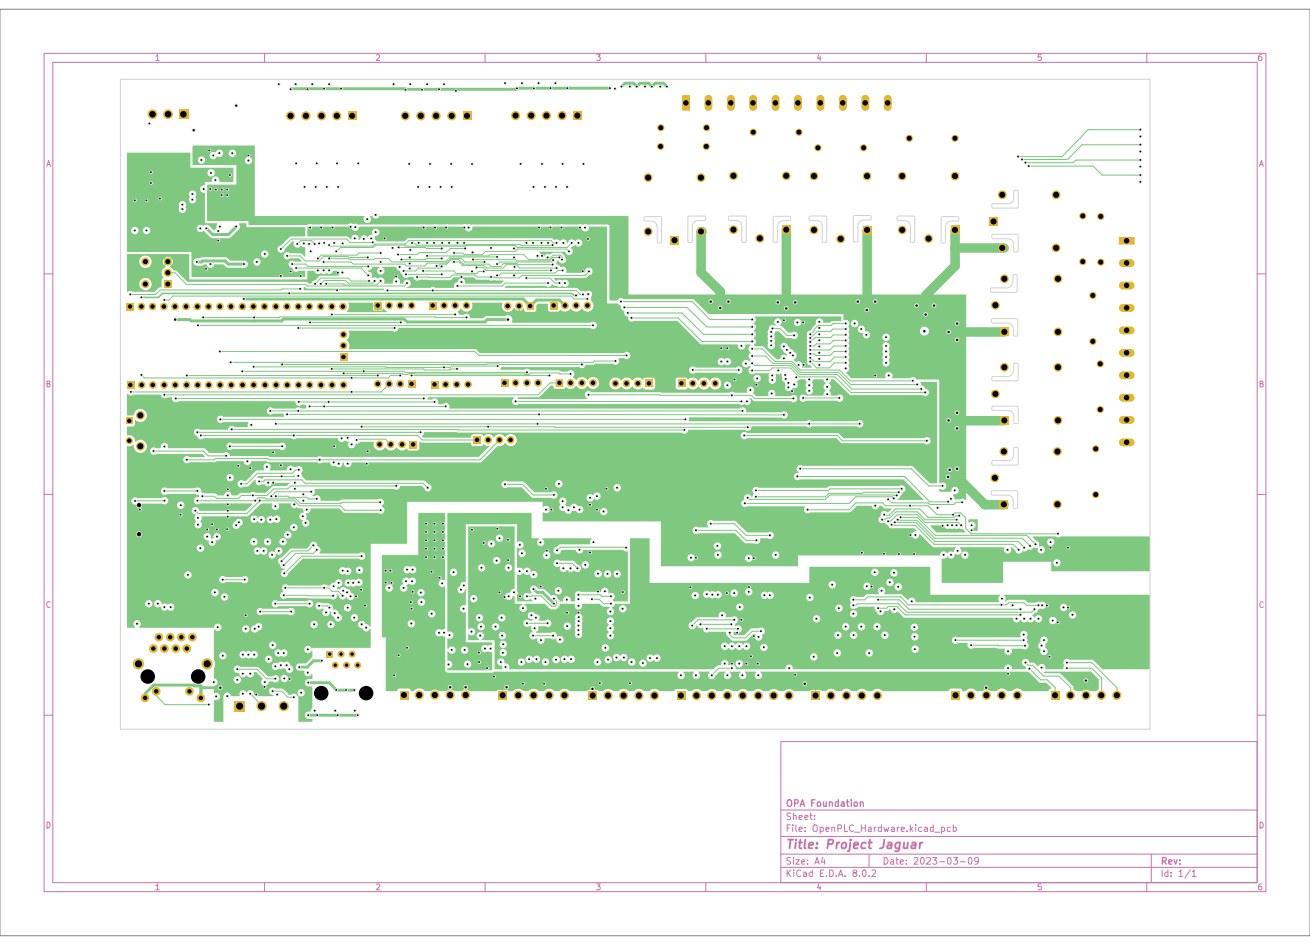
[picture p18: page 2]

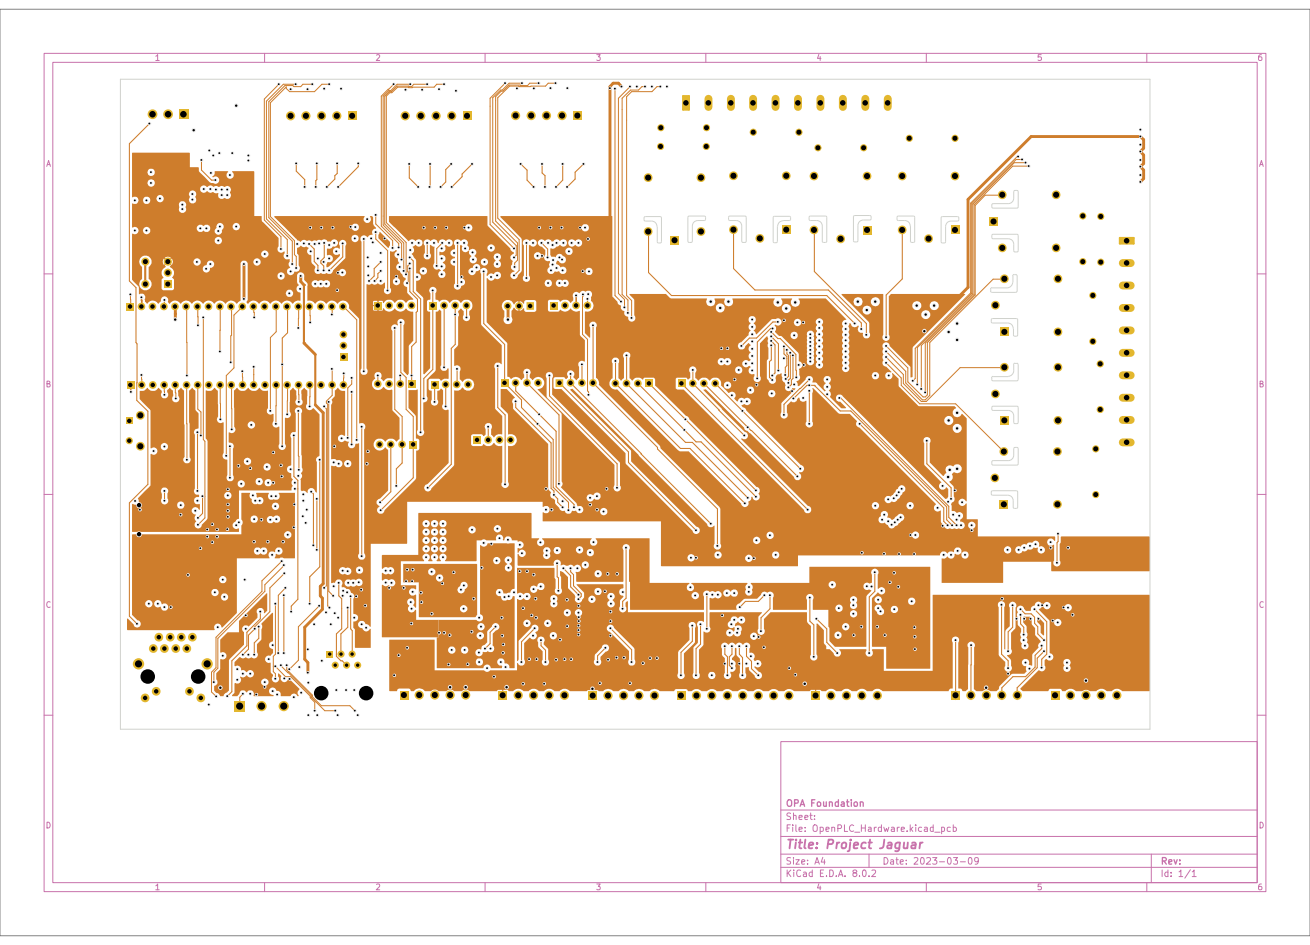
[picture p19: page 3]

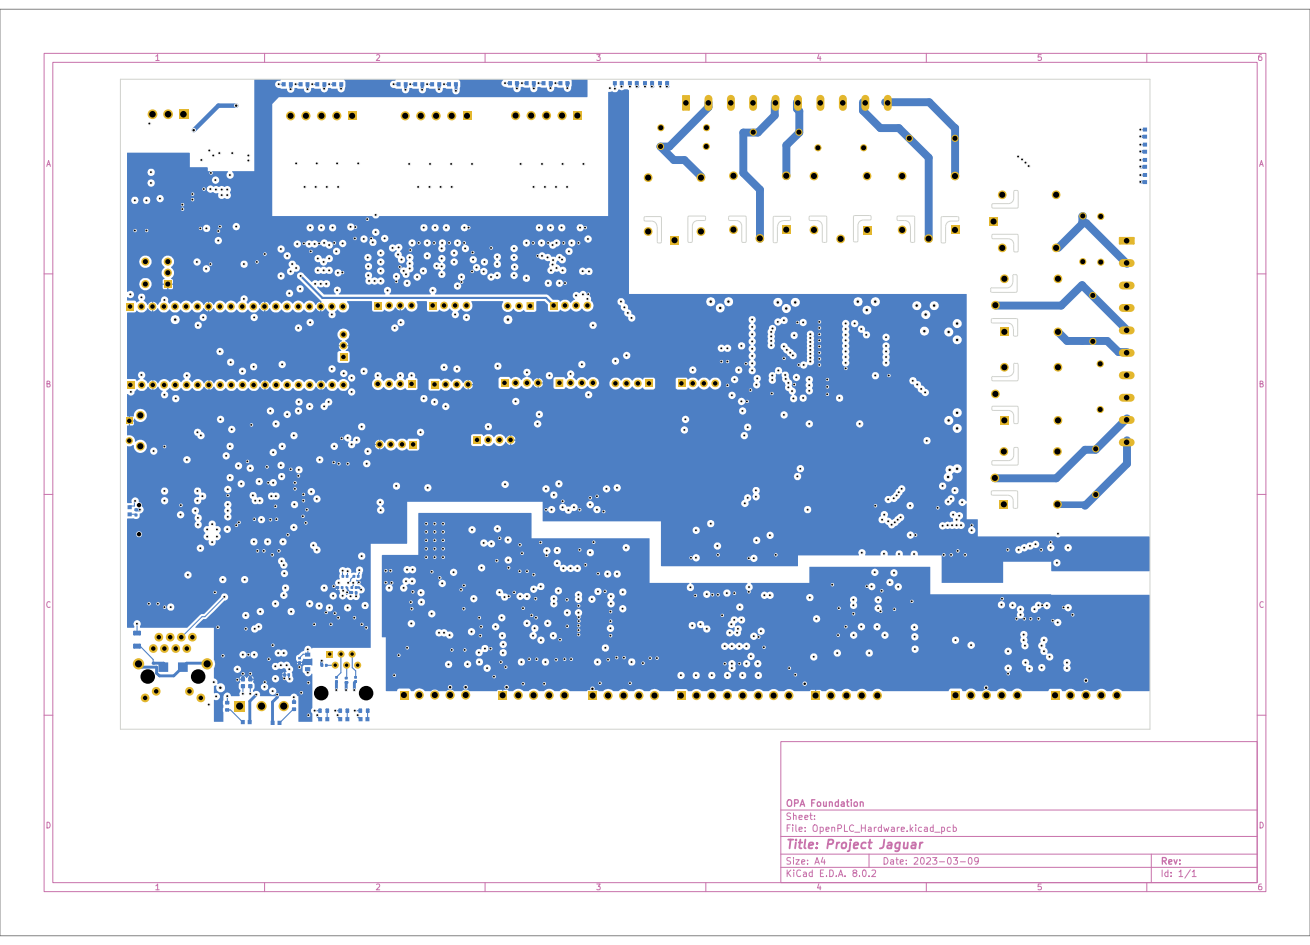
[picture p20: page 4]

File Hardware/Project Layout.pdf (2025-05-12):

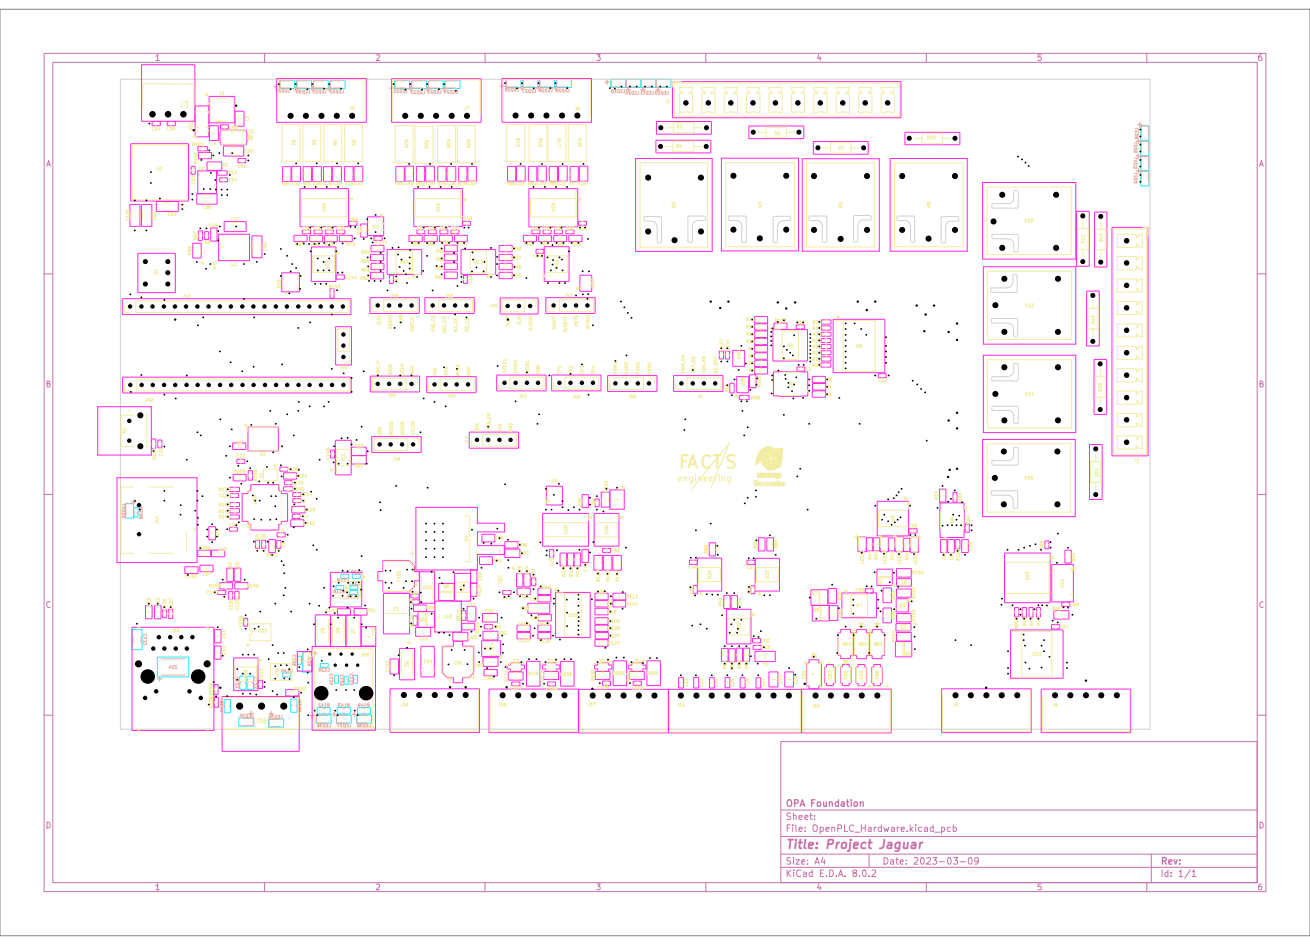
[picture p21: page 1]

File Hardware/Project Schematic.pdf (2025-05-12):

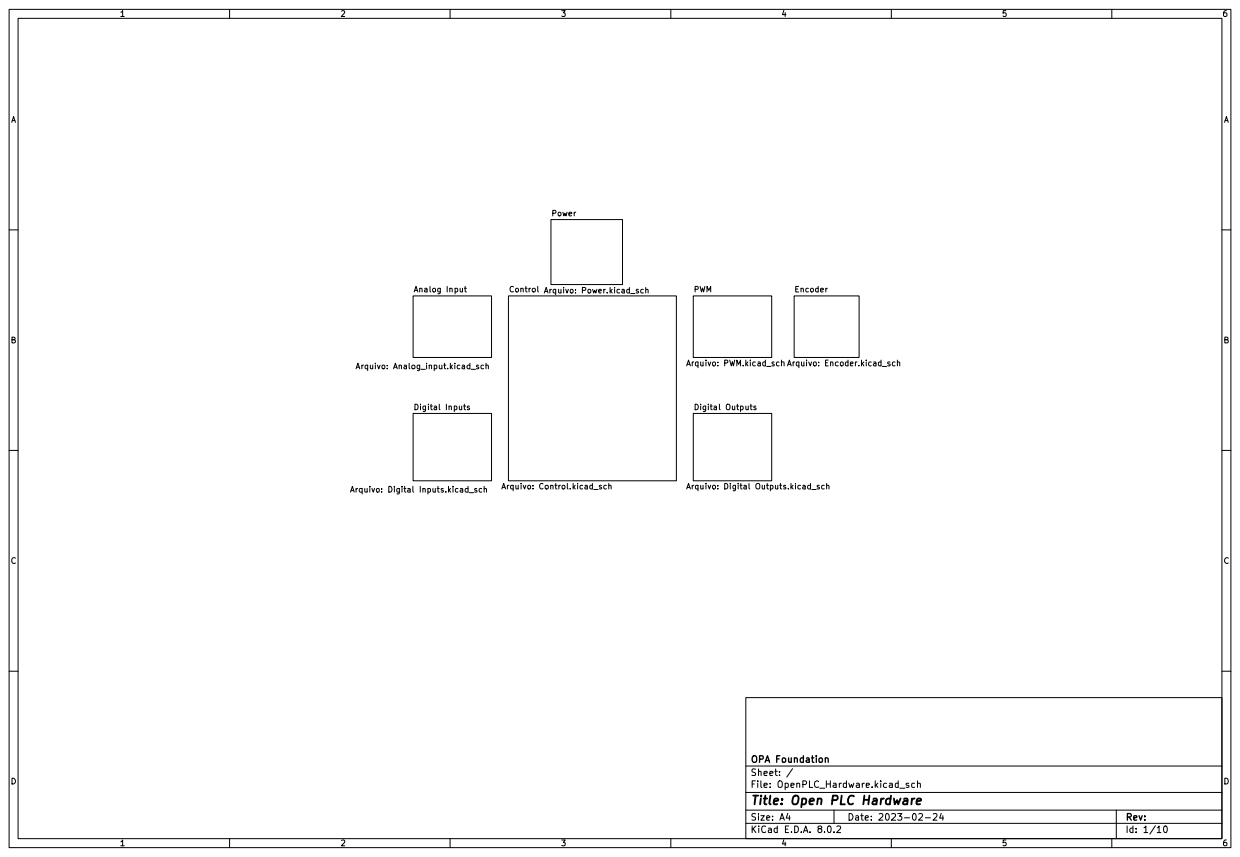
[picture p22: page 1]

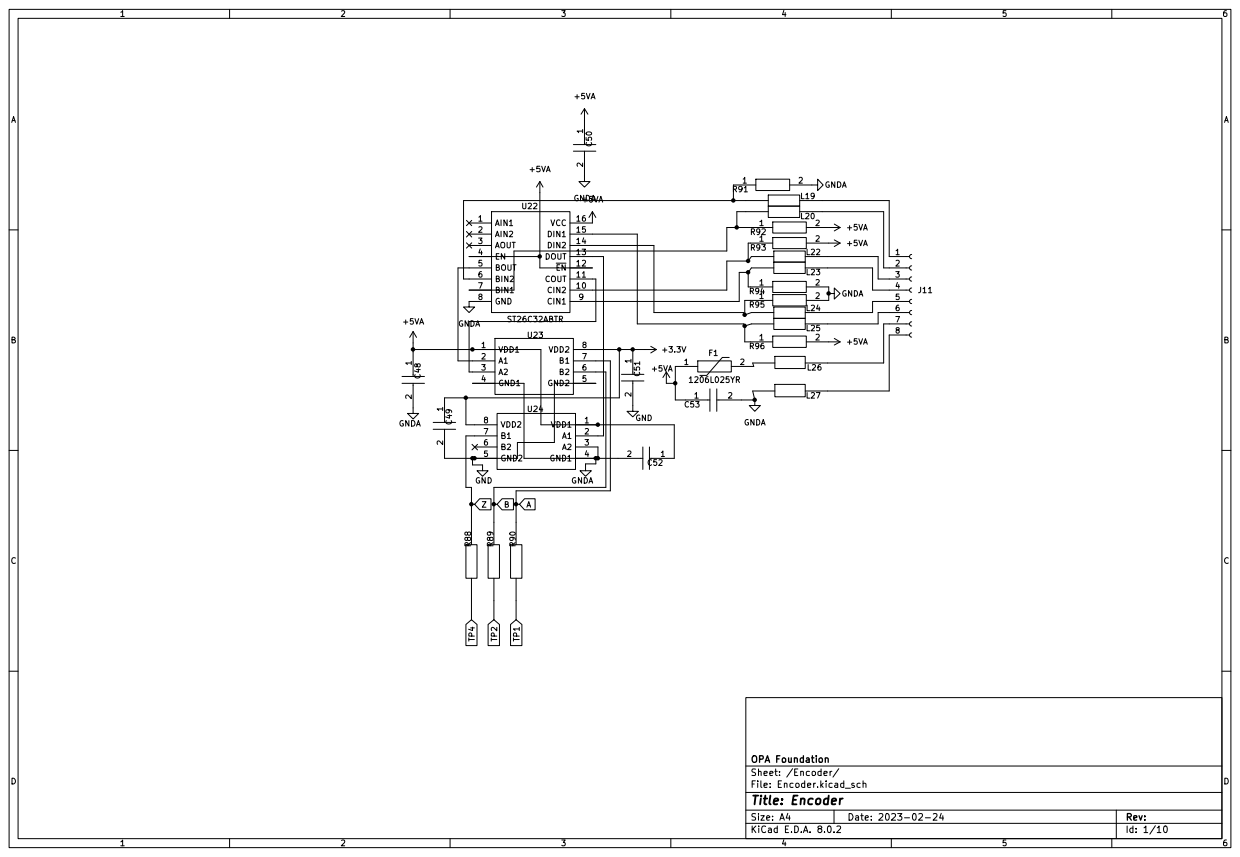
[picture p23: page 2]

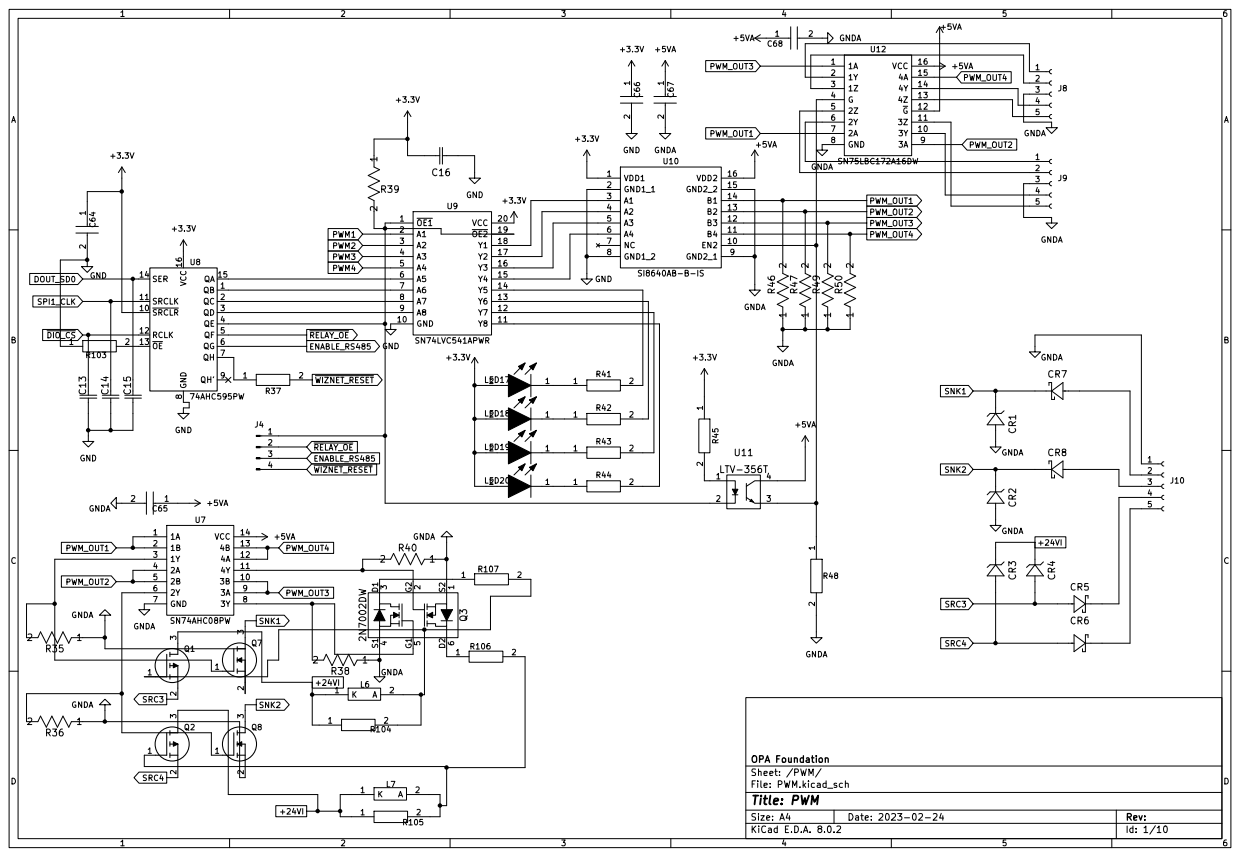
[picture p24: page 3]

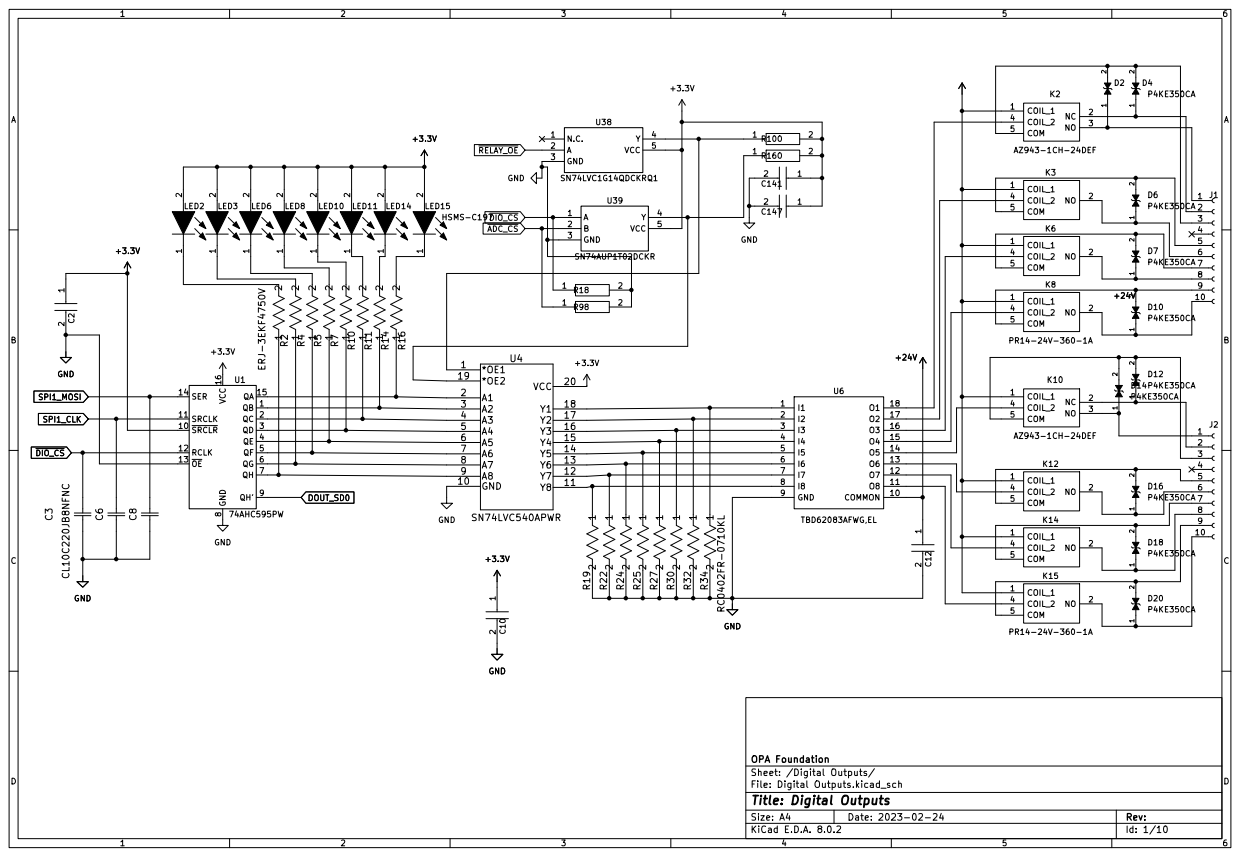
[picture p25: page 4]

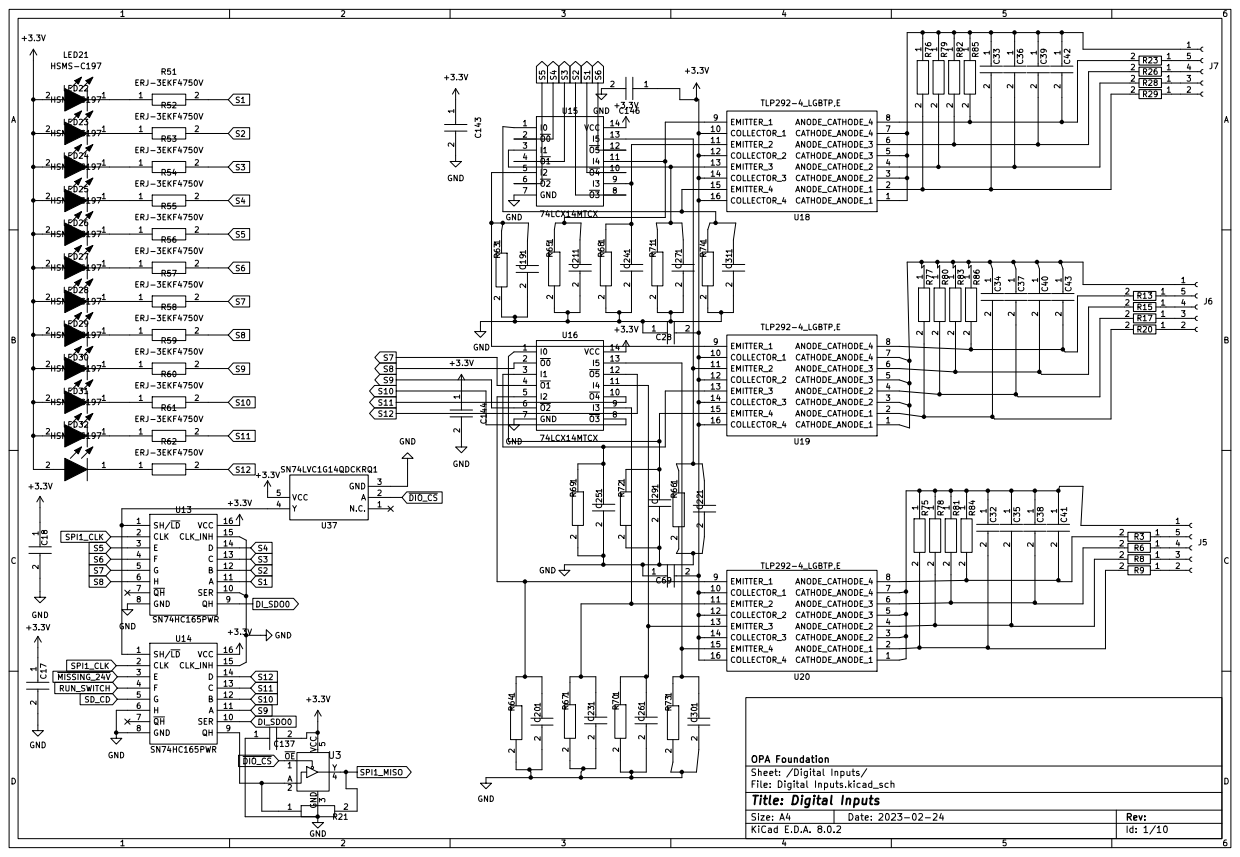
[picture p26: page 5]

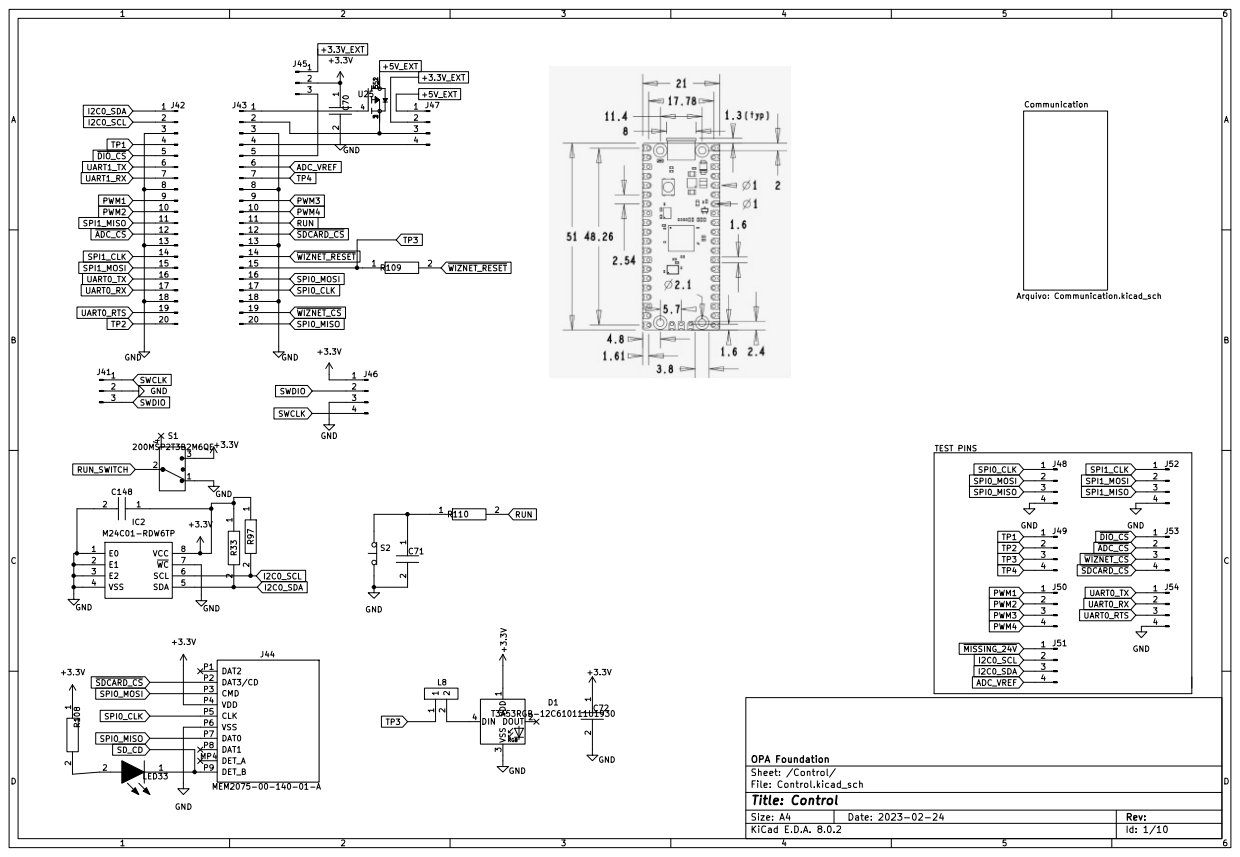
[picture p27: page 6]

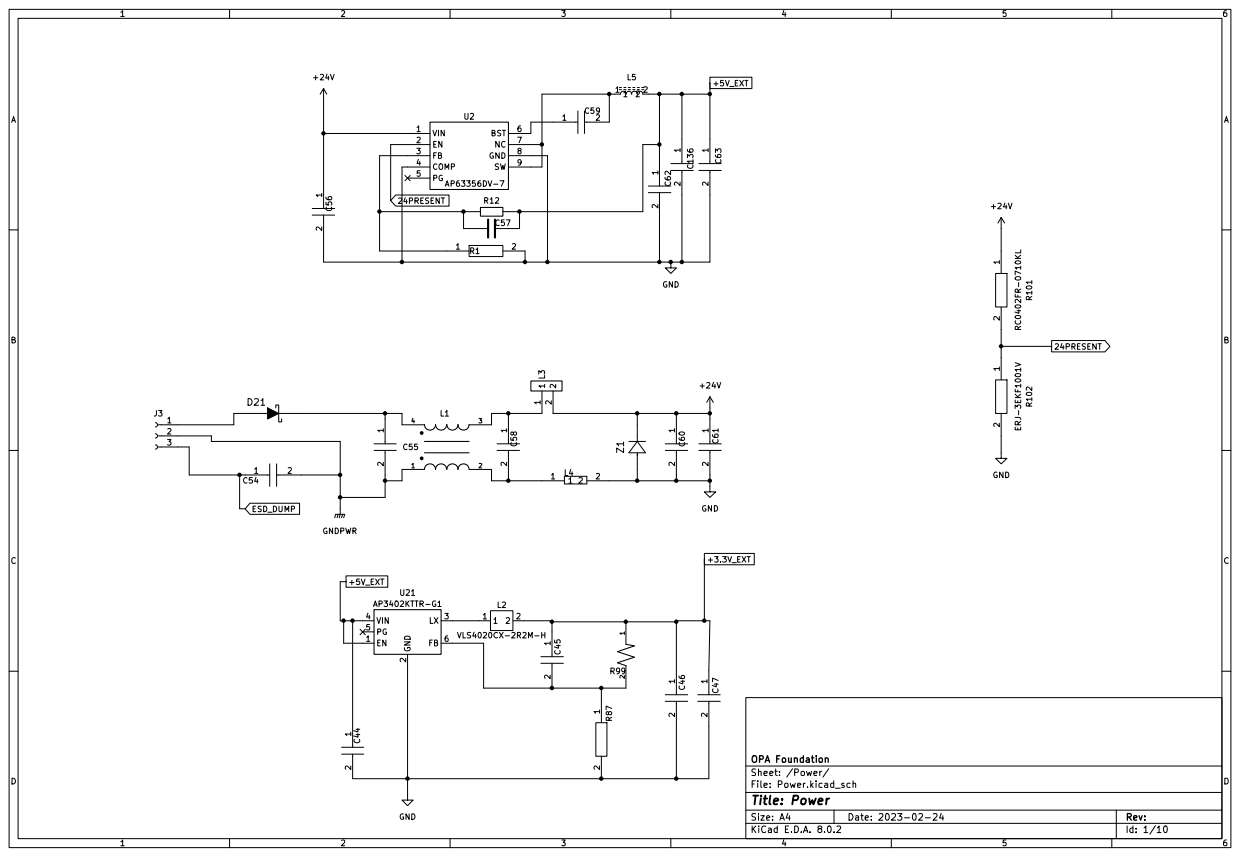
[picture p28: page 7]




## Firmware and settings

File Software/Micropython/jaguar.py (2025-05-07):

import machine
import utime
import network

class DigitalIO:
    """ Classe para manipulação de entradas e saídas digitais via SPI. """
    def __init__(self, spi_id=0, sck=10, mosi=11, miso=8, dio_cs=3, adc_cs=9, num_inputs=12, num_outputs=8):
        self.spi = machine.SPI(spi_id, baudrate=50000, polarity=0, phase=0,
                               sck=machine.Pin(sck), mosi=machine.Pin(mosi), miso=machine.Pin(miso))
        self.dio_cs = machine.Pin(cs, machine.Pin.OUT)
        self.adc_cs = machine.Pin(adc_cs, machine.Pin.OUT)
        self.num_inputs = num_inputs
        self.num_outputs = num_outputs
        self.output_state = 0  # Estado inicial das saídas (todos os bits em 0)
        self.dio_cs.value(1)
        self.adc_cs.value(1)
    
    def __getitem__(self, pin):
        """ Lê o estado de uma entrada digital. """
        if 1 <= pin <= self.num_inputs:
            self.adc_cs.value(1)  # Garante que o ADC está desativado
            self.dio_cs.value(0)
            raw_data = self.spi.read(2)  # Lê os 12 bits das entradas digitais
            self.dio_cs.value(1)
            value = (raw_data[0] << 8 | raw_data[1]) >> (16 - self.num_inputs)
            return (value >> (self.num_inputs - pin)) & 1
        raise IndexError("Entrada digital fora do alcance")
    
    def __setitem__(self, pin, state):
        """ Define o estado de uma saída digital. """
        if 1 <= pin <= self.num_outputs:
            if state:
                self.output_state |= (1 << (self.num_outputs - pin))
            else:
                self.output_state &= ~(1 << (self.num_outputs - pin))
            
            self.adc_cs.value(1)  # Garante que o ADC está desativado
            self.dio_cs.value(0)
            self.spi.write(bytearray([self.output_state]))  # Envia novo estado das saídas
            self.dio_cs.value(1)
        else:
            raise IndexError("Saída digital fora do alcance")

class AnalogInput:
    """ Classe para leitura de entradas analógicas via ADS8688IDBTR. """
      def __init__(self, spi_id=0, sck=10, mosi=11, miso=8, dio_cs=3, adc_cs=9, num_inputs=12, num_outputs=8):
        self.spi = machine.SPI(spi_id, baudrate=50000, polarity=0, phase=0,
                               sck=machine.Pin(sck), mosi=machine.Pin(mosi), miso=machine.Pin(miso))
        self.adc_cs = machine.Pin(adc_cs, machine.Pin.OUT)
        self.dio_cs = machine.Pin(dio_cs, machine.Pin.OUT)
        self.dio_cs.value(1)
        self.adc_cs.value(1)
    
    def __getitem__(self, channel):
        """ Lê o valor do ADC para um canal específico. """
        if 1 <= channel <= 8:
            self.dio_cs.value(1)
            self.adc_cs.value(0)  # Ativa o ADC
            self.spi.write(bytearray([0xC0 | (channel - 1)]))  # Envia comando de leitura
            utime.sleep_us(10)
            value = self.spi.read(2)
            self.adc_cs.value(1)  # Desativa o ADC
            return (value[0] << 8) | value[1]
        raise IndexError("Canal ADC fora do alcance")

class PWMOutput:
    """ Classe para controle de saídas PWM. """
    def __init__(self, pin, freq=1000):
        self.pwm = machine.PWM(machine.Pin(pin))
        self.pwm.freq(freq)
    
    def set_duty_cycle(self, duty):
        """ Define o duty cycle do sinal PWM. """
        self.pwm.duty_u16(int(duty * 65535 / 100))

class Encoder:
    """ Classe para leitura de encoder incremental. """
    def __init__(self, pin_a, pin_b):
        self.pin_a = machine.Pin(pin_a, machine.Pin.IN, machine.Pin.PULL_UP)
        self.pin_b = machine.Pin(pin_b, machine.Pin.IN, machine.Pin.PULL_UP)
        self.count = 0
        self.pin_a.irq(trigger=machine.Pin.IRQ_RISING, handler=self._callback)
    
    def _callback(self, pin):
        """ Callback para contar pulsos do encoder. """
        if self.pin_b.value():
            self.count += 1
        else:
            self.count -= 1
    
    def read(self):
        """ Retorna a contagem do encoder. """
        return self.count

class Ethernet:
    """ Classe para comunicação via Ethernet utilizando W5500. """
    def __init__(self, spi, cs_pin):
        self.nic = network.WIZNET5K(spi, cs=machine.Pin(cs_pin))
    
    def connect(self, timeout=10):
        """ Conecta a rede via DHCP e retorna o IP obtido. """
        self.nic.active(True)  # Ativa a interface Ethernet
        self.nic.ifconfig('dhcp')  # Solicita IP via DHCP
         # Aguarda até obter um IP válido
        for _ in range(timeout):
            ip = self.nic.ifconfig()[0]
            if ip and ip != '0.0.0.0':
                return ip
            time.sleep(1)
    
    def send(self, data):
        """ Envia dados pela rede Ethernet. """
        self.nic.send(data)
    
    def receive(self):
        """ Recebe dados da rede Ethernet. """
        return self.nic.recv(1024)

class RS232:
    """ Classe para comunicação via RS-232. """
    def __init__(self, uart_num=1, baudrate=9600, tx=4, rx=5):
        self.uart = machine.UART(uart_num, baudrate=baudrate, tx=machine.Pin(tx), rx=machine.Pin(rx))
    
    def send(self, data):
        """ Envia dados via RS-232. """
        self.uart.write(data)
    
    def receive(self):
        """ Recebe dados via RS-232. """
        return self.uart.read()

class RS485(RS232):
    """ Classe para comunicação RS-485, herdando de RS-232 e adicionando controle de transmissão. """
    def __init__(self, uart_num=1, baudrate=9600, tx=4, rx=5, de_re=6):
        super().__init__(uart_num, baudrate, tx, rx)
        self.de_re = machine.Pin(de_re, machine.Pin.OUT)
    
    def send(self, data):
        """ Envia dados via RS-485, ativando o transmissor. """
        self.de_re.value(1)
        utime.sleep_ms(1)
        self.uart.write(data)
        utime.sleep_ms(1)
        self.de_re.value(0)
    
    def receive(self):
        """ Recebe dados via RS-485. """
        return self.uart.read()

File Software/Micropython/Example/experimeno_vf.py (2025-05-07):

import utime
from machine import SPI, Pin
from umqtt.simple import MQTTClient
from jaguar import DigitalIO, PWMOutput, Encoder, Ethernet

# Configuração do hardware
pwm_motor = PWMOutput(pin=6)  # Controle de velocidade do motor

# Configuração da comunicação Ethernet
spi = SPI(0,2_000_000, mosi=Pin(19),miso=Pin(16),sck=Pin(18))
eth = Ethernet(spi, cs_pin=17)
eth.connect()

# Configuração do PID
class PIDController:
    def __init__(self, setpoint, kp, ki, kd, integral_max):
        self.setpoint = setpoint
        self.kp = kp
        self.ki = ki
        self.kd = kd
        self.integral_max = integral_max
        self.prev_error = 0
        self.integral = 0

    def compute(self, feedback_value):
        error = self.setpoint - feedback_value
        self.integral += error
        # Limita a parte integral para evitar integral windup
        self.integral = min(max(self.integral, -self.integral_max), self.integral_max)
        derivative = error - self.prev_error
        output = self.kp * error + self.ki * self.integral + self.kd * derivative
        self.prev_error = error
        return output

RPMdesejado = 750
KP = 0.035 
KI = 0.01 
KD = 0.05
INTEGRAL_MAX = 10
duty_cycle = 25

# Criação do objeto PIDController
pid = PIDController(RPMdesejado, KP, KI, KD, INTEGRAL_MAX)

# Configuração do Encoder
tachometerPin = Pin(28, Pin.IN, Pin.PULL_DOWN)
counter = 0

# Função de interrupção do Encoder
def tachometer(pin):
    global counter
    counter += 1
    
tachometerPin.irq(trigger = Pin.IRQ_RISING,
                  handler = tachometer)

# Função de callback para receber mensagens MQTT
def on_message(topic, msg):
    global RPMdesejado, KP, KD, KI, pid
    if topic == b"motor/setpoint":
        print("setpoint atualizado", int(msg))
        RPMdesejado = int(msg)
        pid = PIDController(RPMdesejado, KP, KI, KD, INTEGRAL_MAX)
    elif topic == b"motor/kp":
        KP = float(msg)
        pid = PIDController(RPMdesejado, KP, KI, KD, INTEGRAL_MAX)
    elif topic == b"motor/ki":
        KI = float(msg)
        pid = PIDController(RPMdesejado, KP, KI, KD, INTEGRAL_MAX)
    elif topic == b"motor/kd":
        KD = float(msg)
        pid = PIDController(RPMdesejado, KP, KI, KD, INTEGRAL_MAX)


# ===== COMUNICAÇÃO MQTT =====
BROKER = '192.168.0.22'

def conectar_mqtt():
    cliente = MQTTClient('jaguar', BROKER, port=1883, keepalive=60)
    cliente.set_callback(on_message)
    res = cliente.connect()
    print("Resultado da conexão:", res)  # geralmente 0 = sucesso
    utime.sleep(0.5)
    return cliente

mqtt_client = conectar_mqtt()
utime.sleep(1)
mqtt_client.subscribe(b'motor/setpoint')
mqtt_client.publish("motor/setpoint", str(RPMdesejado))
mqtt_client.subscribe(b'motor/kp')
mqtt_client.publish("motor/kp", str(KP))
mqtt_client.subscribe(b'motor/kd')
mqtt_client.publish("motor/kd", str(KD))
mqtt_client.subscribe(b'motor/ki')
mqtt_client.publish("motor/ki", str(KI))

last_check = utime.ticks_ms()

# Loop principal
while True:
    
    if utime.ticks_diff(utime.ticks_ms(), last_check) > 200:
        try:
            mqtt_client.check_msg()
        except Exception as e:
            print("MQTT erro:", e)
        last_check = utime.ticks_ms()
    
    # Leitura do encoder para cálculo de RPM
    SAMPLING_TIME = 0.25 # in seconds 
    rpm = 0
    i = 0
    while i < 3:
        utime.sleep(SAMPLING_TIME)
        revolutions_per_sampling_time = counter/600
        revolutions_per_sec = revolutions_per_sampling_time/SAMPLING_TIME
        revolutions_per_minute = round(revolutions_per_sec * 60, 0)
        rpm = rpm + revolutions_per_minute
        # reset the counter to zero 
        counter = 0
        i = i + 1

    RPM = rpm/3
    print("RPM: ", int(RPM))
    
# Cálculo do sinal de controle pelo PID
    pid_output = pid.compute(RPM)

# Constante para limitar o aumento gradual
    MAX_INCREMENT = 20
    MAX_DECREMENT = 20

# Cálculo da Nova Compensação
    newduty_cycle = pid_output + duty_cycle

# Limitação do Ciclo de Trabalho para evitar aumento repentino
    if newduty_cycle - duty_cycle > MAX_INCREMENT:
        newduty_cycle = min(duty_cycle + MAX_INCREMENT, 100)
    elif newduty_cycle - duty_cycle < -MAX_DECREMENT:
        newduty_cycle = max(duty_cycle - MAX_DECREMENT, 0)

# Aplicação do Ciclo de Trabalho ao Motor
    pwm_motor.set_duty_cycle(int(newduty_cycle))

# Atualização do ciclo de trabalho atual
    duty_cycle = newduty_cycle
    print("duty_cycle: ", duty_cycle)
    
# Publicação dos dados via MQTT
    mqtt_client.publish("motor/rpm", str(RPM))
    mqtt_client.publish("motor/desejado", str(RPMdesejado))
    mqtt_client.publish("motor/duty", str(duty_cycle))
    

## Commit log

2024-05-21 Update Files
    [06035C222KAT2A.stp, 0603ESDA2-TR2.stp, 0603ZD105KAT2A.stp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]
2025-05-07 Add new files and reorganization
    [06035C222KAT2A.stp, 0603ESDA2-TR2.stp, 0603ZD105KAT2A.stp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]
2025-05-12 Add OpenPLC Files
    [VARIABLES.csv]
